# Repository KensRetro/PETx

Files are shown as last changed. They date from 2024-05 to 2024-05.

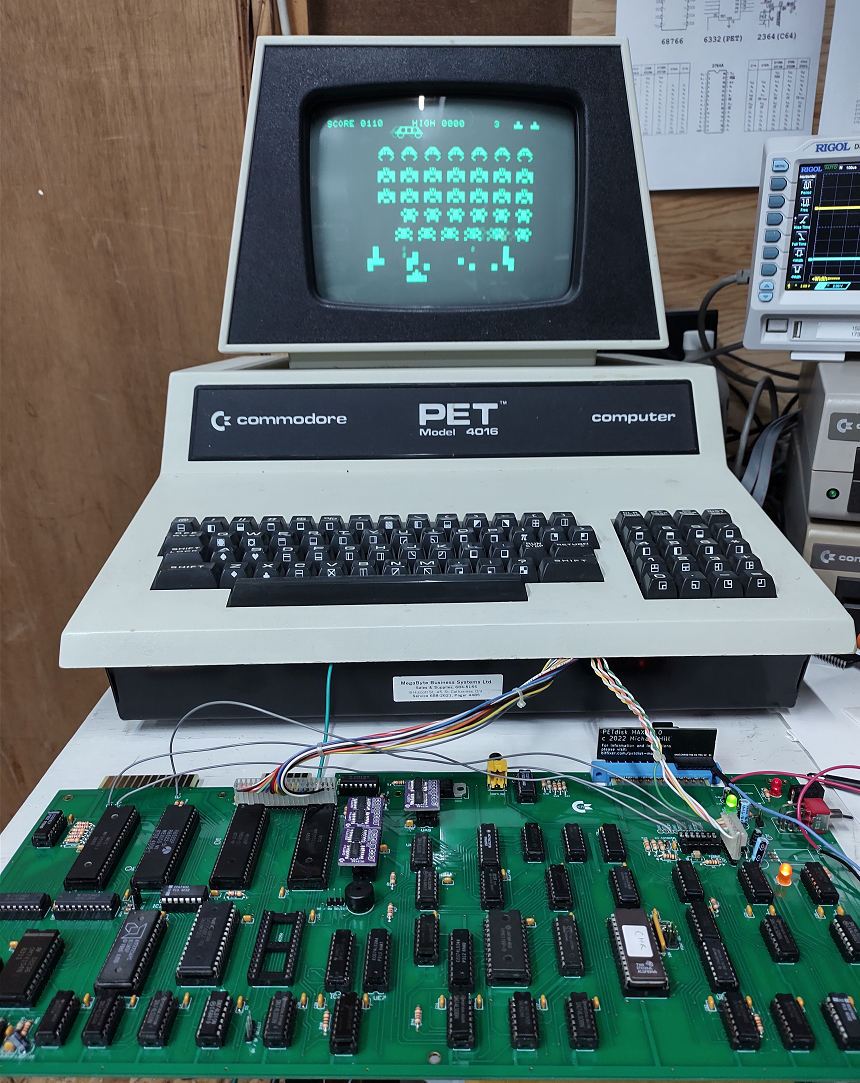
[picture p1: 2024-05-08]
Pictures/Prototype_testing1.png

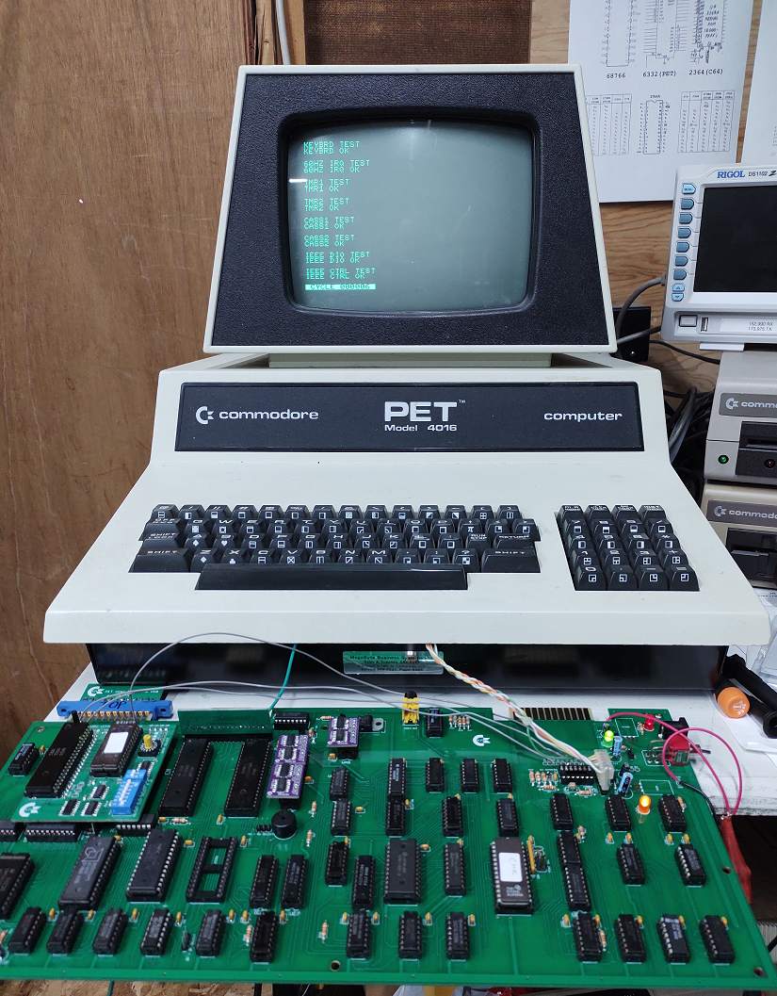
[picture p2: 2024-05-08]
Pictures/Prototype_testing2.png

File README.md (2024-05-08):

# This project is currently partially complete, please read the following carefully and make an informed decision before you attempt to build it.

I like to provide schematics in Eagle (version 7) because that's what I have used for years at work and it's easy to upgrade the files to 
newer versions or Kicad etc.  It's just a comfort thing for me, but if you change to another format please be sure to carefully check 
that everything looks as it should - conversions don't always go cleanly.  

DISCLAIMER: All information is provided 'AS-IS", I have tried to be as accurate as possible but that doesn't mean there are no mistakes. 
Any errors or omissions etc. are your own responsibility.  

# Project Notes : C64 sized PET - PETx

The prototype is based on the the 9 inch screen version of the PET (board #320349) so no CRTC chip is needed.
I added the video circuit similar to the ones posted around the net
It was also decided to go with a more similar to original re-creation as it makes it easier to substitute parts etc. 
and compatibility remains quite good.

# Changes / Updates in this version (PROTOTYPE): 
1. Added connections for RESET (momentary switch)
2. Added NO_ROM line for diagnostics
3. Added peizo buzzer for standard PET sounds
4. Added Video output circuit - HORIZ/VERT/VIDEO signals no longer attached to USER PORT (I left connection points but will need a
   jumper to connect if needed. This was done in order to facilitate routing, these lines to the user port are normally used for a
   video output circuit, since it's already on-board, it's not likely needed)
5. Added GRAPHIC signal to USER PORT (similar to 12" screen versions)
6. Removed memory expansion connections, definitely won't fit on the board and no known expansion units will fit in the case anyway
7. Changed Video RAM to a single 6116 chip instead of 2 x 2114 (availability)
8. Change ROM set to a single chip, added necessary decoding logic so I/O chip memory is not replaced.
9. Added a jumper to allow multiple ROM sets built in (could be connected to a switch)
10. Changed RAM to a single chip of 32K, this also allowed removal of +12V and -5V supplies and associated components saving a lot of space.
11. Removed CASSETTE #2 as it is rarely used, connection points are still available but no driver for the tape motor was included.
    Connection would have to be wired off the board if needed.
12. Added a couple sets of connection points for +5V and GND for add-ons (normally CASSETTE #1/2 was used for this)
13. Added optional 2nd RAM chip mapped into 9000-FFFF range, jumper (or switch configurable) for only being active over 9000-AFFF or 9000-FFFF for soft ROM option
14. Added option for 2nd RAM (9000-FFFF) to be "READ ONLY" or "READ WRITE"
15. Terminated unused gates to minimize potential noise.
16. Changed ROM socket to allow use of SST39SF010A as well as 27256 (4 ROM sets, Flash ROM, externally programmable)
17. Changed Character ROM to allow more fonts and use of SST39SF010A as well as 27xxx series Eproms.
18. Added power switch & connector that should fit into the existing C64 bracket  (if used)
19. Added access to unused RAM in 8000 area (8400-8FFF)
    
# Potential upgrades not currently incorporated:
(Feel free to suggest others)
1. Add a writable latch that controls some of the dipswitch selectable features above
    
# More Notes:
This project is a PET 2001, 9 inch screen version (started with schematic 320349). This model was chosen for 2 reasons, 
first, a CRTC chip is not required and second, it outputs a near standard video signal with the included interface.
The Intent was to make it fit into a C64 / VIC-20 case.
In order to Achieve this a reduced footprint was needed, so the changes above were implemented.
The parallel and Cassette #1 ports were designed to line up in the same place as the C64/VIC20 version.
The video output appears where the RF output jack was on the C64. This area is in the cartridge slot on the VIC20
The IEEE port appears where the C64 cartridge port was and covers the left 2/3 of the VIC 20 cartridge area.
The placements mean that no/few modifications are needed to the case of the C64 or VIC 20 to fit the board in.
Unfortunately, the power switch and joystick area ends up wide open, with the power switch and power cord coming out in that area.
Perhaps a 3D printed cover could be fashioned as a replacement.
Many other possible upgrades were considered but due to a lack of space and complexity, were rejected (for the prototype run at least).
Perhaps other additions or changes could be incorporated in a future version.
This project depends on the Commodore original prints being correct, some minor corrections were caught, but they were used as a base to start.
The Chip ID's on the silkscreen are those from the original PET layout and start with Uxxx, Chips that start with ICxx are additions or changes 
that have been incorporated to slim the footprint or facilitate routing.
Various keyboard options were considered but again, for the prototype at least, were sticking with a standard C64/VIC20 keyboard and a patched 
version of the edit ROM (or some other available hardware solution)

# BEFORE YOU BUILD:
Some of the parts are near impossible to find, specifically 3446 chips, 74177 chips, and 74154 chips in a DIP package. 
I have a replacement sub-board for the 3446 chips in another repository that has been tested successfully.
You can use 74197 chips as a direct replacement for the 74177, but they are very rare as well.
You can use a newer version of the 74154 chip but it seems to only be available in a SMT version, therefore an adaptor board may need to be created.

# PROTOTYPE VERSION:
This version has been created and tested.  Some small errors were corrected with bodge wires and an added chip and and it seems to function well and passes the diagnostic 
cartridge tests consistantly.

# RELEASE VERSION:
This version HAS NOT been created or tested (I didn't really need another hanging around)
The errors have been corrected in the schematic and board files and Gerbers have been created.

Changes to this version (REV.1) also include the following:
1) Added solder jumpers to allow WD6502 to be used
2) Changed Power supply to 1 regulator
   
TO DO:
1. check/fix alignment of mounting holes to C64 case (Not checked or tested in VIC20 case at this time)

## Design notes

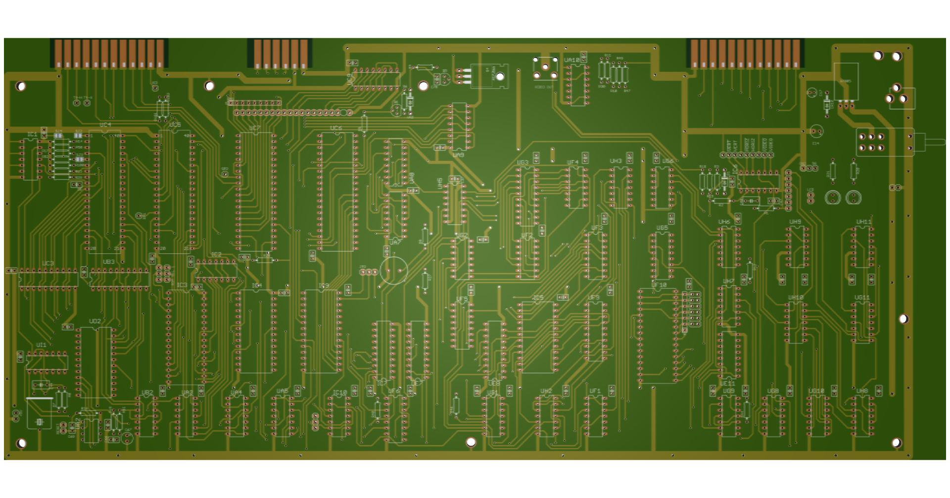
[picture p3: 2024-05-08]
Pictures/board(Rev1).png

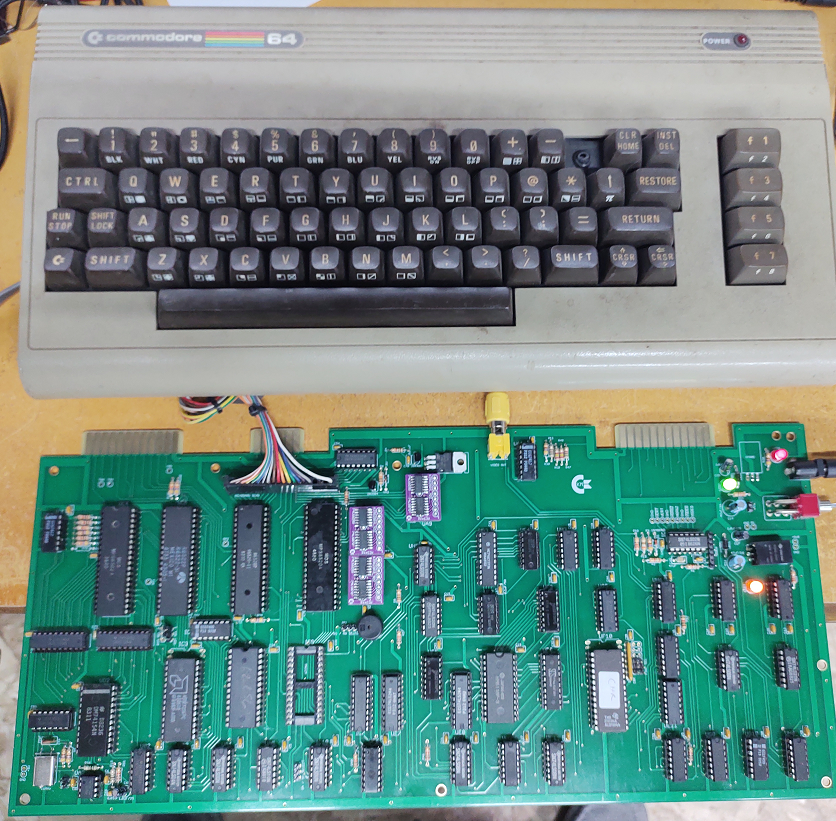
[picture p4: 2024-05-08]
Pictures/Prototype.png

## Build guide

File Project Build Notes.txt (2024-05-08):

PETx Construction and testing notes:

(*** = Updateed note)

You will need basic soldering and electronic skills to complete this project!!!

*** including an EPROM burner or EEPROM writer if that's what you wish to use, the board should accept 27xxx series EPROMS, SST39SF010A Flash memory or compatible, for both the main ROM and Character Generator with a jumper setting - let me know and I will send the configuration details for which ever you wish to use.

At this time I have tried the board with limited variety of optional chips, some seem more critical than others, please be aware this may affect your results.
The board has passed 100 cycles of the Commodore diagnostic test and has been tried with a 2031 disk drive and PETdisk MAX successfully.
Various games have been tested using both the standard PET keyboard and with a revised ROM, a C64 keyboard.
The C64 keyboard solution seems to need a bit more work for my liking.

*** The replacement edit ROM I found online which is supposed to substitute for a C64 style keyboard leaves a lot to be desired. There seems to be no access to shifted characters and the run/stop key doesn't work (however the K key seems to work in it's place to stop execution for some reason)  If you can test with an actual PET keyboard to start it may be beneficial.  I have 2 options to correct this, first, we can try to fix the current replacement ROM or I have created a small secondary project to replace the PET keyboard with a PC (PS2 style) keyboard that seems to function quite well - Details in another repository
FYI: if you use the C64 keyboard, use right shift and F1 to move and space to fire in Space Invaders :)

There are a few rare (obsolete) chips that you will need to source to complete this project, Sorry but I can't help, I have no spares either.
Attached is the parts list, please make sure you can get the necessary parts (at a price you are comfortable with) BEFORE ordering.

The board seems to be a bit finicky about certain chips, I had to try a different brand and speed or RAM chips to get things to work properly (slower RAM worked better, not sure why), but i'm looking into it.

*** I found the issue with the RAM.  Basically there was a small timing issue which, if you are interested, you can learn about in this video : https://www.youtube.com/watch?v=i_wrxBdXTgM (start around 22:00 if you don't want to watch the whole thing)  - Ben Eater has produced a selection of really great videos dealing with building around a 6502, I enjoyed watching these and some of his other well explained videos.  The issue was fixed exactly as Ben fixed it (he's actually used the exact same chips as I have, coincedentally) by adding an extra gate into the circuit. 

Be prepared to do a lot of soldering, it's all through hole so it's easy, but it's a large board and it's a good idea to do the job carefully and well to avoid issues.
I'm still trying low power versions of most chips (awaiting another parts order) to try and get the power supply less loaded.

*** I swapped out MOST of the chips for 74HCTxxx versions and it brought the power consumption down from 1.0 Amp to around 600 mA (on the 5V rail), my supply feeding the board which is now modified for a single regulator actually reads around 380 mA @ 9VDC input to the board. NOTE: There were a few chips that did not seem to work well as HCT (or that I could not find HCT replacement for) so they remain the normal ones.  Interestingly and as a bonus, most HCT versions seemd to be less expensive than their regular counterparts. 

With the factory designated chip versions, the board requires about 1 amp @ 5VDC - I designed it with 2 (2 amp) regulators because the original board had 2.
I found out this is not necessary and with a jumper you can get it down to 1. The regulator is good up to 15 Volts, so a 1 amp supply at 10-12VDC should do it.

There are some chip substitutions that might be easier to find:
For 74177 you can use 74197 - I found DM74197N chips - a little more power needed but basically the same chip.
For 74LS157 I used 74LS257 chips I happen to have on-hand
For 74154 you might have a hard time finding the 28 pin DIP needed, SMT versions seem readily available. 
I have a converter board for these in another repository
For MC3446N (IEEE drivers) I made a converter board to substitute that seems to work well, less drive but unless you are hooking up many devices it likely won't matter.
I have a few of those left, let me know if you need them, (no charge,) 3 are needed for the project
You'll also need a 6502, 6522 and 2 of 6520 chips - These also are getting rare.

A few other parts may need to be figured out or are optional:
such as then Power jack, power switch, on board LED's, expansion RAM (NOTE: so far this option is untested)

*** I have tested the expansion RAM and with the same fix as is needed for the main RAM, plus 1 other minor tweak, it seems to work well. It is entirely optional but will give you RAM from $8800 - $AFFF with the ability to switch to read only, allowing you to load option ROMS in this area and make them appear as read-only to the system.  I have also enabled the excess RAM in the video circuit (by default) to allow access to RAM from the end of video $8400 - $8800.  I have not tried the RAM above $B000, it's there and should record anything written to it (poked in) but will not respond until you do 2 things: 1. Disable the normal ROM (using the !NOROM signal) and 2. Enable the RAM to respond with the correct jumper.  I can explain in detail if you wish, just let me know,  This switch is a bit tricky as it requires the cpu to not be accessing ROM while it switches, so a small bit of assembler code is required with a 2 pole switch to change the mentioned signals; I have tested this minimally with success.

Build Notes:

I used sockets for EVERY chip, this is a good idea! Please use good quality sockets for the 6502/6522/6520's/RAM/ROM/CHARGEN sockets at a minimum - Machine pin type seem to work well for chips that may be changed occasionally (especially during troubleshooting).
*** Machine pin sockets work great for NEW parts, not so well for de-soldered ones, something to keep in mind. 
Also note that some component footprints might not be quite correct (capacitor sizes and that sort of thing) as I used footprints that suited the parts I had on-hand.
Some (bottom) mounting holes don't quite line up with C64 case.

Holes are provided to be able to use the metal bracket off a C64 board (power switch end) if you can find one.
A jumper (and a cut trace) is needed on the RAM chip
1 Regulator needed only (install jumper to other footprint)
Buzzer doesn't quit fit properly, need to adjust footprint

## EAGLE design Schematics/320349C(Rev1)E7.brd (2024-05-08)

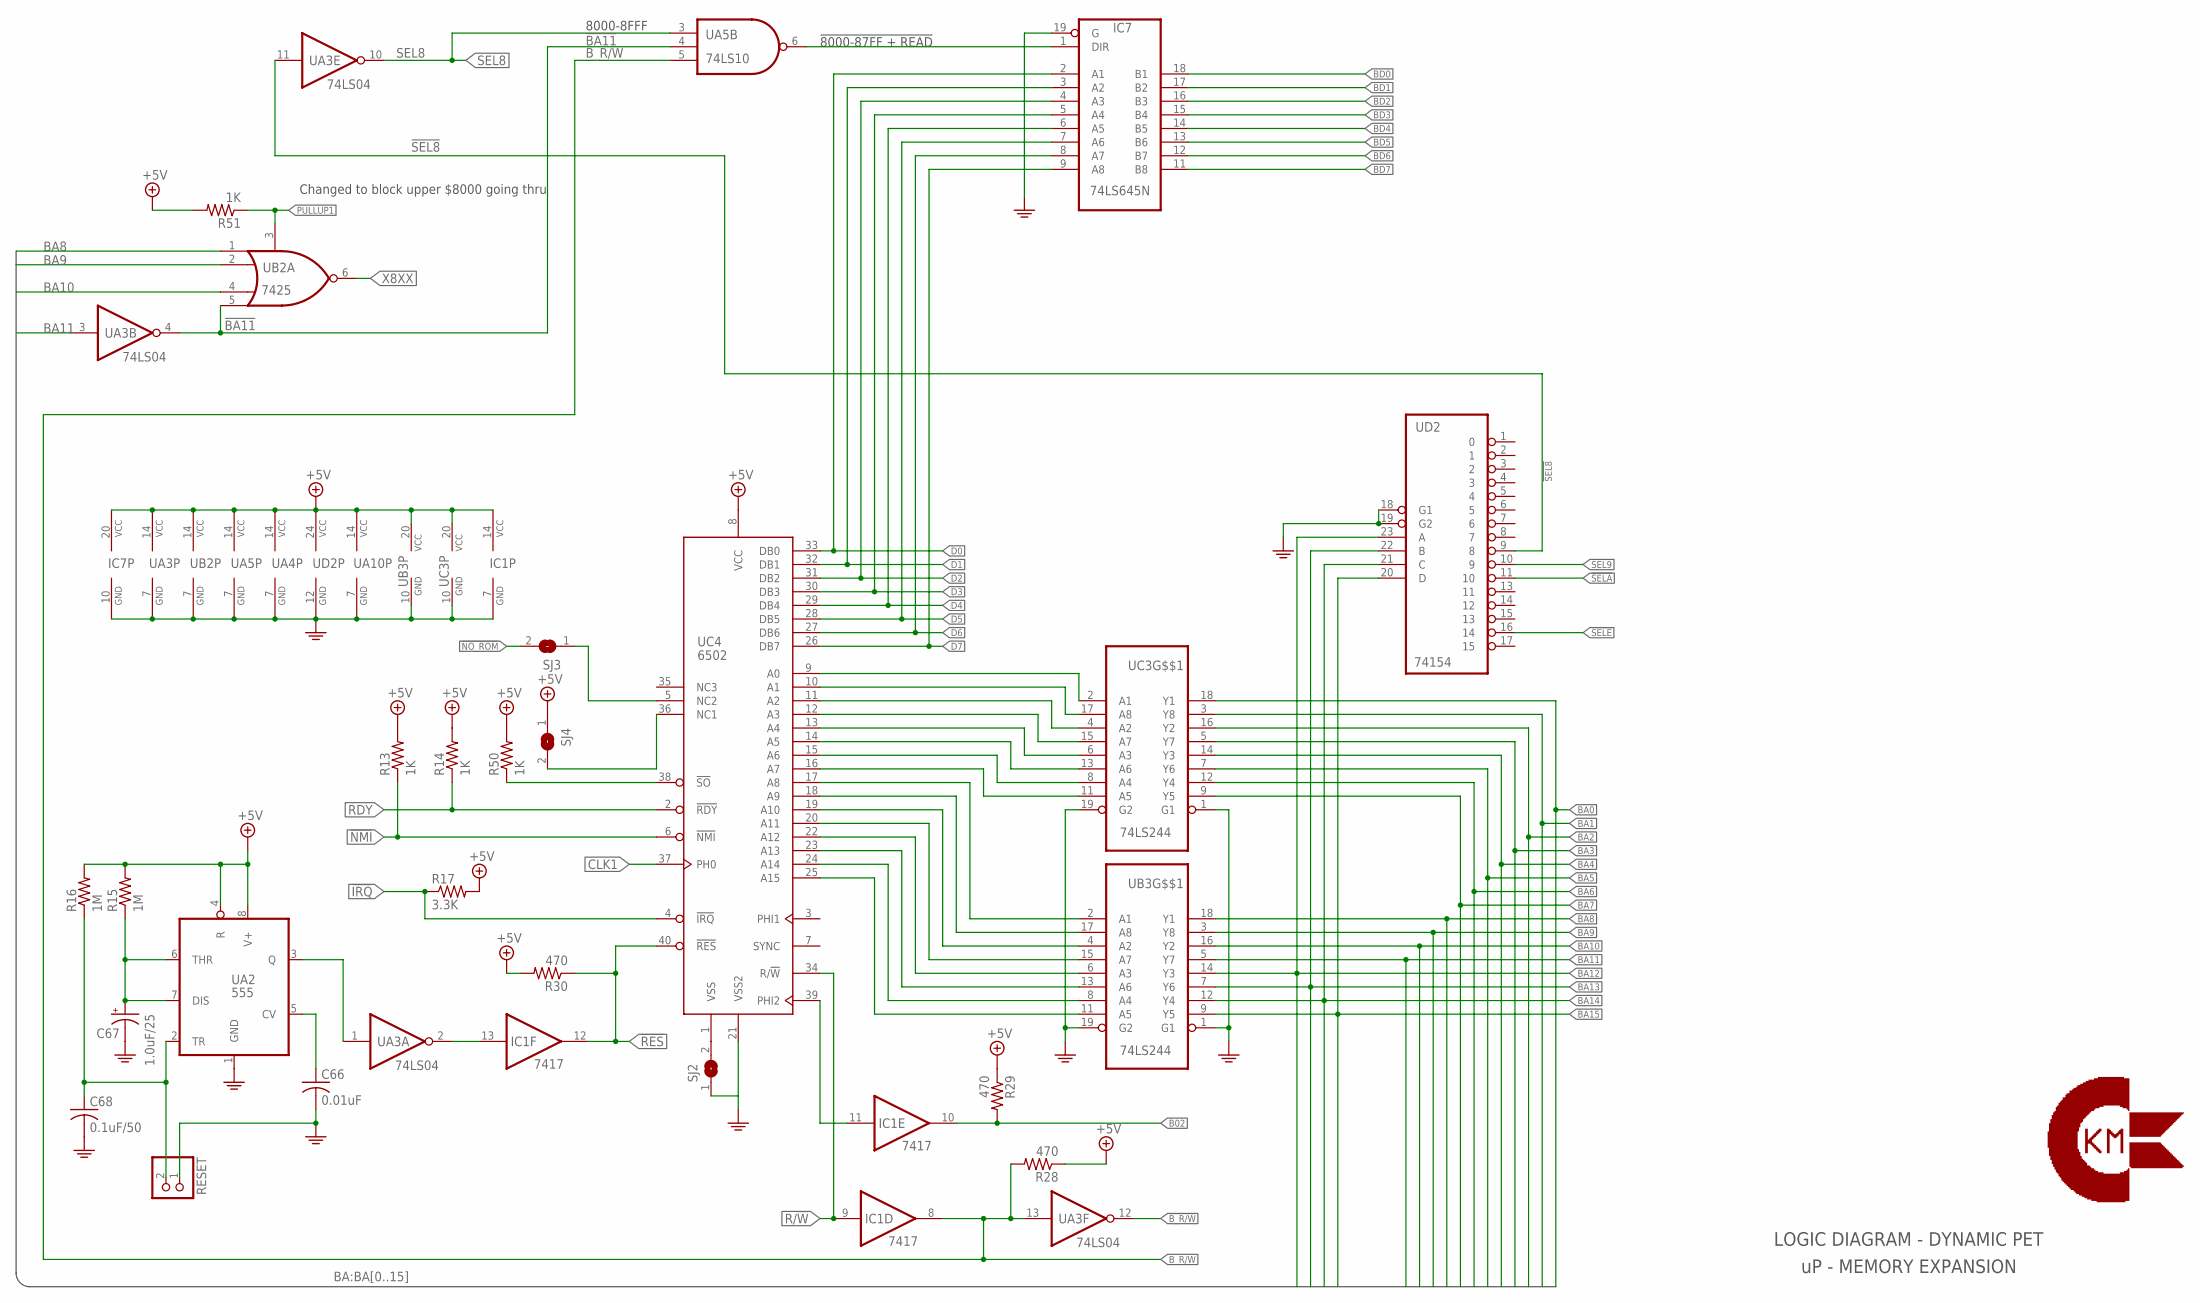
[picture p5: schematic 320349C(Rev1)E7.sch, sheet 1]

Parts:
C66: 0.01uF; C025-025X050
C67: 1.0uF/25; E2,5-5
C68: 0.1uF/50; C025-025X050
IC1: 7417; DIL14
IC7: 74LS645N; DIL20
R13, R14, R50, R51: 1K; 0207/10
R15, R16: 1M; 0207/10
R17: 3.3K; 0207/10
R28, R29, R30: 470; 0207/10
RESET: PINHD-1X2; 1X02
SJ2, SJ3, SJ4: SJ
UA2: 555; DIL08
UA3: 74LS04; DIL14
UA4: 74LS00; DIL14
UA5: 74LS10; DIL14
UA10: 7417; DIL14
UB2: 7425; DIL14
UB3: 74LS244; DIL20
UC3: 74LS244; DIL20
UC4: 6502; DIP40
UD2: 74154; DIL24-6

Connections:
!BA11: UA3.4 (O), UA5.4 (I1), UB2.5 (I3); also elsewhere on the board
!B_R/W: UA3.12 (O); also elsewhere on the board
!IRQ: R17.1, UC4.4 (!IRQ); also elsewhere on the board
!NMI: R13.1, UC4.6 (!NMI)
!NO_ROM: SJ3.2; also elsewhere on the board
!RES: IC1.12 (O), R30.1, UC4.40 (!RES); also elsewhere on the board
!SEL8: UA3.11 (I), UD2.9 (8); also elsewhere on the board
!SEL9: UD2.10 (9); also elsewhere on the board
!SELA: UD2.11 (10); also elsewhere on the board
!SELE: UD2.16 (14); also elsewhere on the board
+5V: IC1.14 (VCC), IC7.20 (VCC), R13.2, R14.2, R15.2, R16.2, R17.2, R28.1, R29.1, R30.2, R50.2, R51.2, SJ4.1, UA2.4 (R), UA2.8 (V+), UA3.14 (VCC), UA4.14 (VCC), UA5.14 (VCC), UA10.14 (VCC), UB2.14 (VCC), UB3.20 (VCC), UC3.20 (VCC), UC4.8 (VCC), UD2.24 (VCC); also elsewhere on the board
AB0: UC3.2 (A1), UC4.9 (A0)
AB1: UC3.17 (A8), UC4.10 (A1)
AB2: UC3.4 (A2), UC4.11 (A2)
AB3: UC3.15 (A7), UC4.12 (A3)
AB4: UC3.6 (A3), UC4.13 (A4)
AB5: UC3.13 (A6), UC4.14 (A5)
AB6: UC3.8 (A4), UC4.15 (A6)
AB7: UC3.11 (A5), UC4.16 (A7)
AB8: UB3.2 (A1), UC4.17 (A8)
AB9: UB3.17 (A8), UC4.18 (A9)
AB10: UB3.4 (A2), UC4.19 (A10)
AB11: UB3.15 (A7), UC4.20 (A11)
AB12: UB3.6 (A3), UC4.22 (A12)
AB13: UB3.13 (A6), UC4.23 (A13)
AB14: UB3.8 (A4), UC4.24 (A14)
AB15: UB3.11 (A5), UC4.25 (A15)
B02: IC1.10 (O), R29.2; also elsewhere on the board
BA0: UC3.18 (Y1); also elsewhere on the board
BA1: UC3.3 (Y8); also elsewhere on the board
BA2: UC3.16 (Y2); also elsewhere on the board
BA3: UC3.5 (Y7); also elsewhere on the board
BA4: UC3.14 (Y3); also elsewhere on the board
BA5: UC3.7 (Y6); also elsewhere on the board
BA6: UC3.12 (Y4); also elsewhere on the board
BA7: UC3.9 (Y5); also elsewhere on the board
BA8: UB2.1 (I0), UB3.18 (Y1); also elsewhere on the board
BA9: UB2.2 (I1), UB3.3 (Y8); also elsewhere on the board
BA10: UB2.4 (I2), UB3.16 (Y2); also elsewhere on the board
BA11: UA3.3 (I), UB3.5 (Y7); also elsewhere on the board
BA12: UB3.14 (Y3), UD2.23 (A); also elsewhere on the board
BA13: UB3.7 (Y6), UD2.22 (B); also elsewhere on the board
BA14: UB3.12 (Y4), UD2.21 (C); also elsewhere on the board
BA15: UB3.9 (Y5), UD2.20 (D); also elsewhere on the board
BD0: IC7.18 (B1); also elsewhere on the board
BD1: IC7.17 (B2); also elsewhere on the board
BD2: IC7.16 (B3); also elsewhere on the board
BD3: IC7.15 (B4); also elsewhere on the board
BD4: IC7.14 (B5); also elsewhere on the board
BD5: IC7.13 (B6); also elsewhere on the board
BD6: IC7.12 (B7); also elsewhere on the board
BD7: IC7.11 (B8); also elsewhere on the board
B_R/W: IC1.8 (O), R28.2, UA3.13 (I), UA5.5 (I2); also elsewhere on the board
CLK1: UC4.37 (PH0); also elsewhere on the board
CLK2: IC1.11 (I), UC4.39 (PHI2)
D0: IC7.2 (A1), UC4.33 (DB0); also elsewhere on the board
D1: IC7.3 (A2), UC4.32 (DB1); also elsewhere on the board
D2: IC7.4 (A3), UC4.31 (DB2); also elsewhere on the board
D3: IC7.5 (A4), UC4.30 (DB3); also elsewhere on the board
D4: IC7.6 (A5), UC4.29 (DB4); also elsewhere on the board
D5: IC7.7 (A6), UC4.28 (DB5); also elsewhere on the board
D6: IC7.8 (A7), UC4.27 (DB6); also elsewhere on the board
D7: IC7.9 (A8), UC4.26 (DB7); also elsewhere on the board
GND: C66.2, C67.-, C68.2, IC1.7 (GND), IC7.10 (GND), IC7.19 (G), RESET.1, SJ2.1, UA2.1 (GND), UA3.7 (GND), UA4.7 (GND), UA5.7 (GND), UA10.7 (GND), UB2.7 (GND), UB3.1 (G1), UB3.10 (GND), UB3.19 (G2), UC3.1 (G1), UC3.10 (GND), UC3.19 (G2), UC4.21 (VSS2), UD2.12 (GND), UD2.18 (G1), UD2.19 (G2); also elsewhere on the board
unnamed: IC7.1 (DIR), UA5.6 (O)
unnamed: R50.1, UC4.38 (!SO)
unnamed: C66.1, UA2.5 (CV)
unnamed: C67.+, R15.1, UA2.6 (THR), UA2.7 (DIS)
unnamed: C68.1, R16.1, RESET.2, UA2.2 (TR)
unnamed: IC1.13 (I), UA3.2 (O)
unnamed: UA2.3 (Q), UA3.1 (I)
unnamed: SJ3.1, UC4.5 (NC2)
unnamed: SJ4.2, UC4.36 (NC1)
unnamed: SJ2.2, UC4.1 (VSS)
PULLUP1: R51.1, UB2.3 (G); also elsewhere on the board
R/!W: IC1.9 (I), UC4.34 (R/!W); also elsewhere on the board
RDY: R14.1, UC4.2 (!RDY)
SEL8: UA3.10 (O), UA5.3 (I0); also elsewhere on the board
X8XX: UB2.6 (O); also elsewhere on the board

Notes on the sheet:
LOGIC DIAGRAM - DYNAMIC PET
uP - MEMORY EXPANSION
8000-8FFF
!8000-87FF + READ
Changed to block upper $8000 going thru

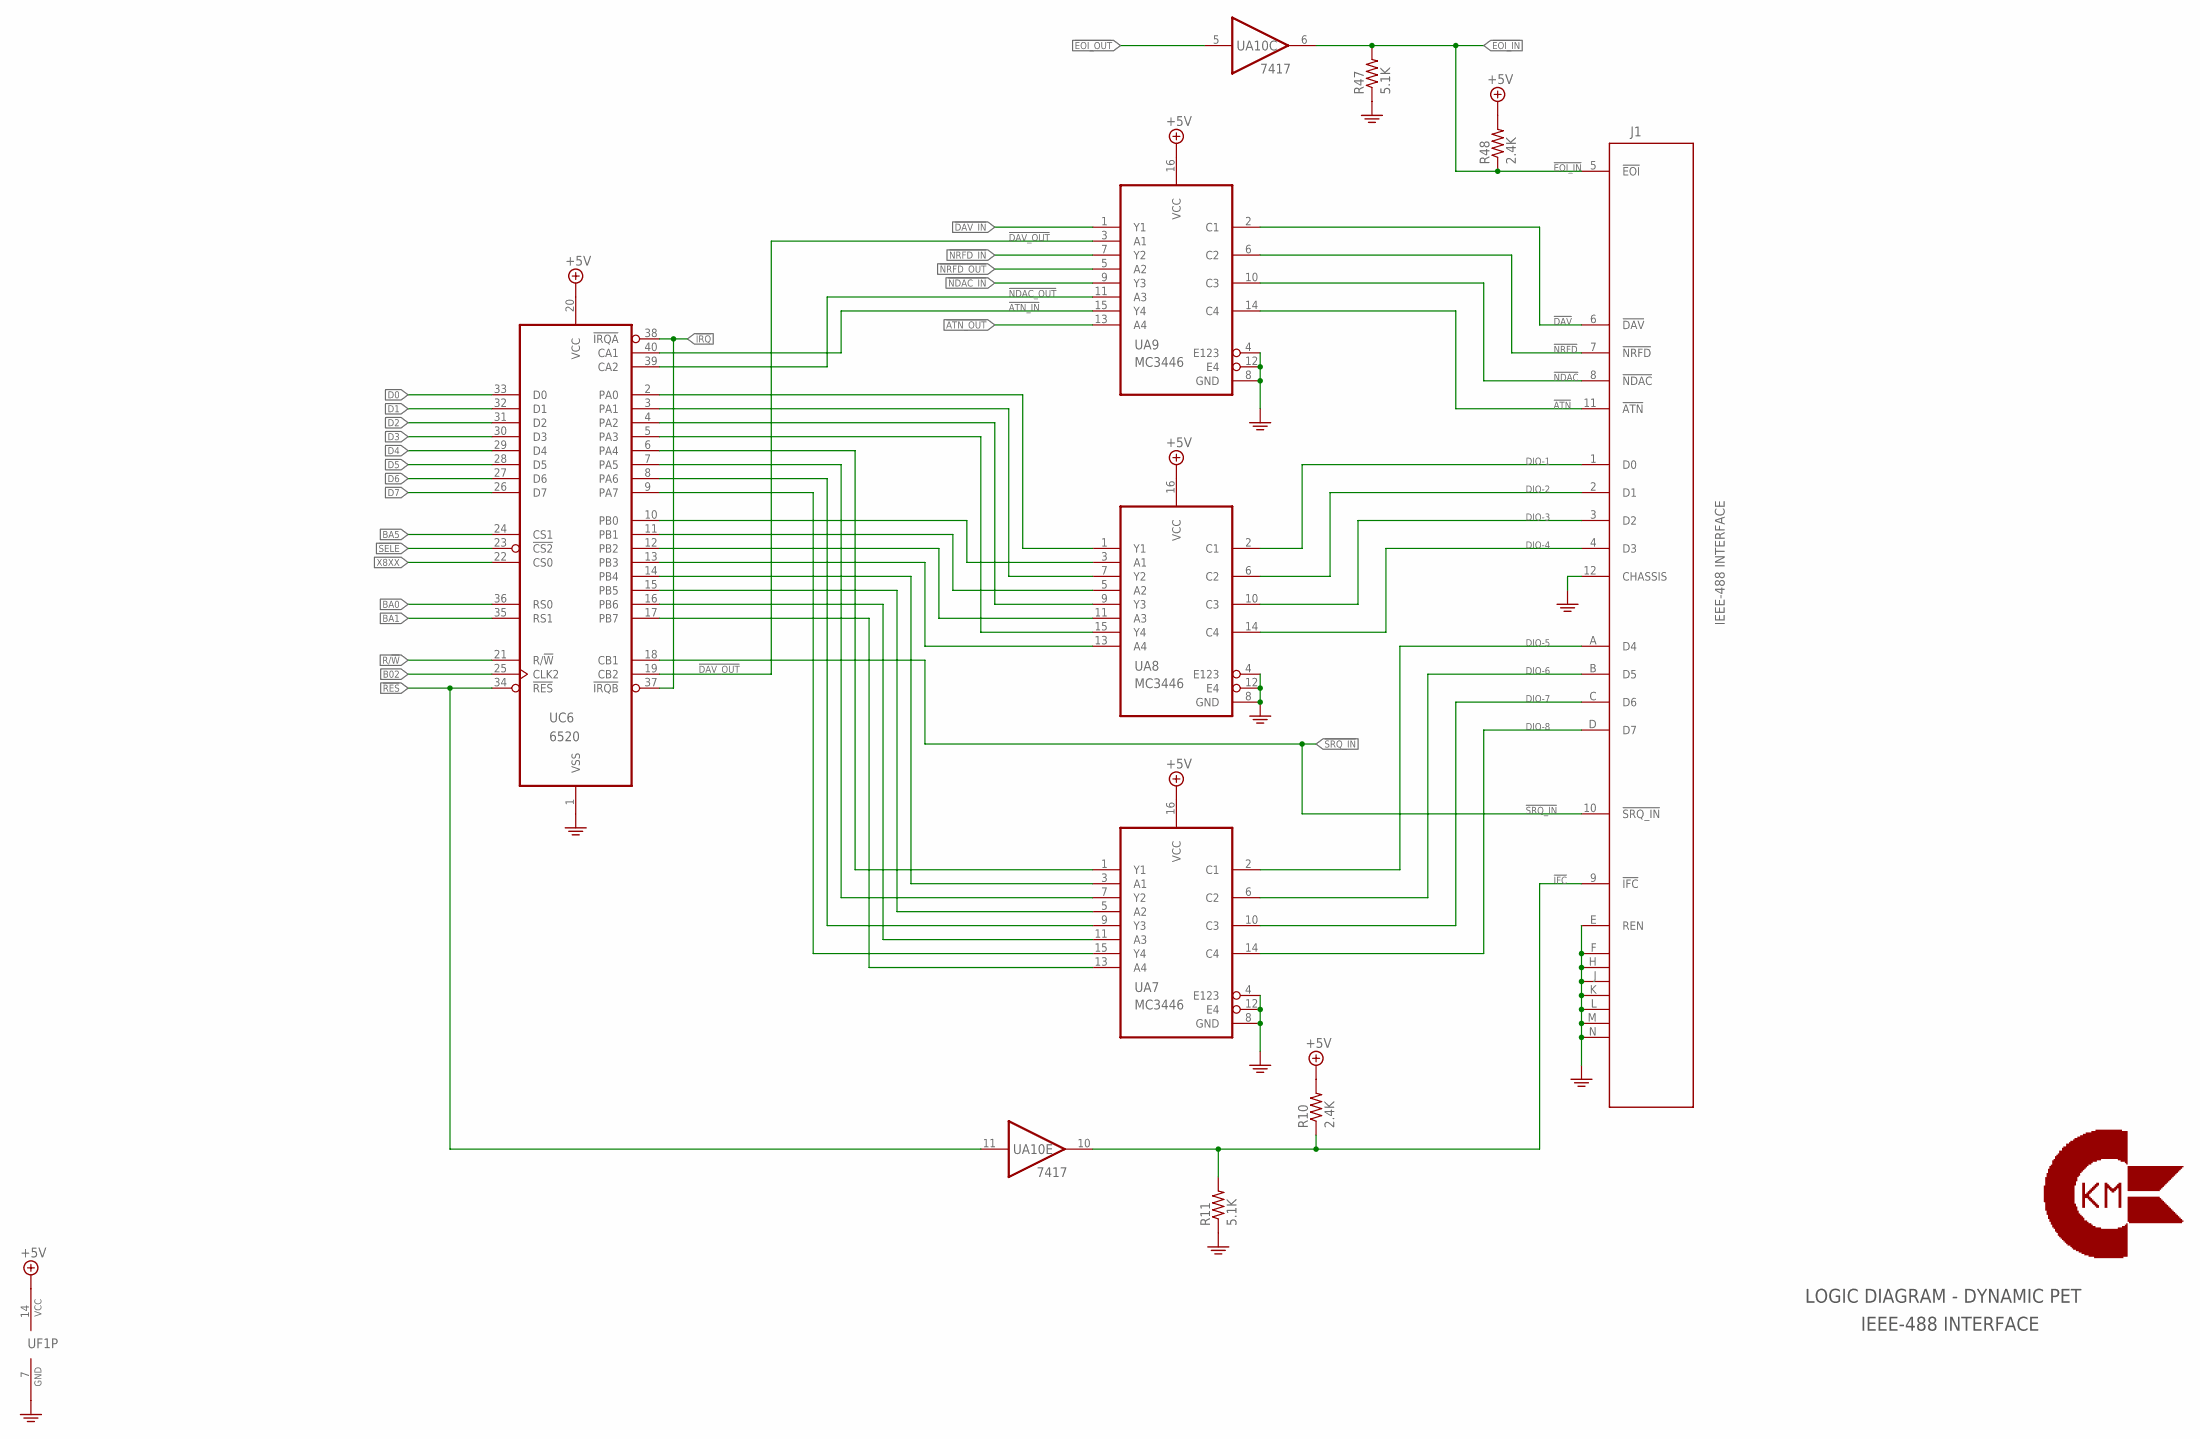
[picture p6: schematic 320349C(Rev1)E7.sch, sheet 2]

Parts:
J1: IEEE-488 INTERFACE; UPS24EDGE
R10, R48: 2.4K; 0207/10
R11, R47: 5.1K; 0207/10
U$32: CBM-XL
UA7, UA8, UA9: MC3446; DIL16
UA10: 7417; DIL14
UC6: 6520; DIL40
UF1: 74LS08; DIL14

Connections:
!ATN: J1.11 (!ATN), UA9.14 (C4)
!ATN_IN: UA9.15 (Y4), UC6.40 (CA1)
!ATN_OUT: UA9.13 (A4); also elsewhere on the board
!DAV: J1.6 (!DAV), UA9.2 (C1)
!DAV_IN: UA9.1 (Y1); also elsewhere on the board
!DAV_OUT: UA9.3 (A1), UC6.19 (CB2)
!EOI_IN: J1.5 (!EOI), R47.2, R48.1, UA10.6 (O); also elsewhere on the board
!EOI_OUT: UA10.5 (I); also elsewhere on the board
!IFC: J1.9 (!IFC), R10.1, R11.2, UA10.10 (O)
!IRQ: UC6.37 (!IRQB), UC6.38 (!IRQA); also elsewhere on the board
!NDAC: J1.8 (!NDAC), UA9.10 (C3)
!NDAC_IN: UA9.9 (Y3); also elsewhere on the board
!NDAC_OUT: UA9.11 (A3), UC6.39 (CA2)
!NRFD: J1.7 (!NRFD), UA9.6 (C2)
!NRFD_IN: UA9.7 (Y2); also elsewhere on the board
!NRFD_OUT: UA9.5 (A2); also elsewhere on the board
!RES: UA10.11 (I), UC6.34 (!RES); also elsewhere on the board
!SELE: UC6.23 (!CS2); also elsewhere on the board
!SRQ_IN: J1.10 (!SRQ_IN), UC6.18 (CB1); also elsewhere on the board
+5V: R10.2, R48.2, UA7.16 (VCC), UA8.16 (VCC), UA9.16 (VCC), UC6.20 (VCC), UF1.14 (VCC); also elsewhere on the board
B02: UC6.25 (CLK2); also elsewhere on the board
BA0: UC6.36 (RS0); also elsewhere on the board
BA1: UC6.35 (RS1); also elsewhere on the board
BA5: UC6.24 (CS1); also elsewhere on the board
D0: UC6.33 (D0); also elsewhere on the board
D1: UC6.32 (D1); also elsewhere on the board
D2: UC6.31 (D2); also elsewhere on the board
D3: UC6.30 (D3); also elsewhere on the board
D4: UC6.29 (D4); also elsewhere on the board
D5: UC6.28 (D5); also elsewhere on the board
D6: UC6.27 (D6); also elsewhere on the board
D7: UC6.26 (D7); also elsewhere on the board
DI-1: UA8.1 (Y1), UC6.2 (PA0)
DI-2: UA8.7 (Y2), UC6.3 (PA1)
DI-3: UA8.9 (Y3), UC6.4 (PA2)
DI-4: UA8.15 (Y4), UC6.5 (PA3)
DI-5: UA7.1 (Y1), UC6.6 (PA4)
DI-6: UA7.7 (Y2), UC6.7 (PA5)
DI-7: UA7.9 (Y3), UC6.8 (PA6)
DI-8: UA7.15 (Y4), UC6.9 (PA7)
DIO-1: J1.1 (D0), UA8.2 (C1)
DIO-2: J1.2 (D1), UA8.6 (C2)
DIO-3: J1.3 (D2), UA8.10 (C3)
DIO-4: J1.4 (D3), UA8.14 (C4)
DIO-5: J1.A (D4), UA7.2 (C1)
DIO-6: J1.B (D5), UA7.6 (C2)
DIO-7: J1.C (D6), UA7.10 (C3)
DIO-8: J1.D (D7), UA7.14 (C4)
DO-1: UA8.3 (A1), UC6.10 (PB0)
DO-2: UA8.5 (A2), UC6.11 (PB1)
DO-3: UA8.11 (A3), UC6.12 (PB2)
DO-4: UA8.13 (A4), UC6.13 (PB3)
DO-5: UA7.3 (A1), UC6.14 (PB4)
DO-6: UA7.5 (A2), UC6.15 (PB5)
DO-7: UA7.11 (A3), UC6.16 (PB6)
DO-8: UA7.13 (A4), UC6.17 (PB7)
GND: J1.12 (CHASSIS), J1.E (REN), J1.F (18), J1.H (19), J1.J (20), J1.K (21), J1.L (22), J1.M (23), J1.N (24), R11.1, R47.1, UA7.4 (E123), UA7.8 (GND), UA7.12 (E4), UA8.4 (E123), UA8.8 (GND), UA8.12 (E4), UA9.4 (E123), UA9.8 (GND), UA9.12 (E4), UC6.1 (VSS), UF1.7 (GND); also elsewhere on the board
R/!W: UC6.21 (R/!W); also elsewhere on the board
X8XX: UC6.22 (CS0); also elsewhere on the board

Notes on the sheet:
LOGIC DIAGRAM - DYNAMIC PET
IEEE-488 INTERFACE

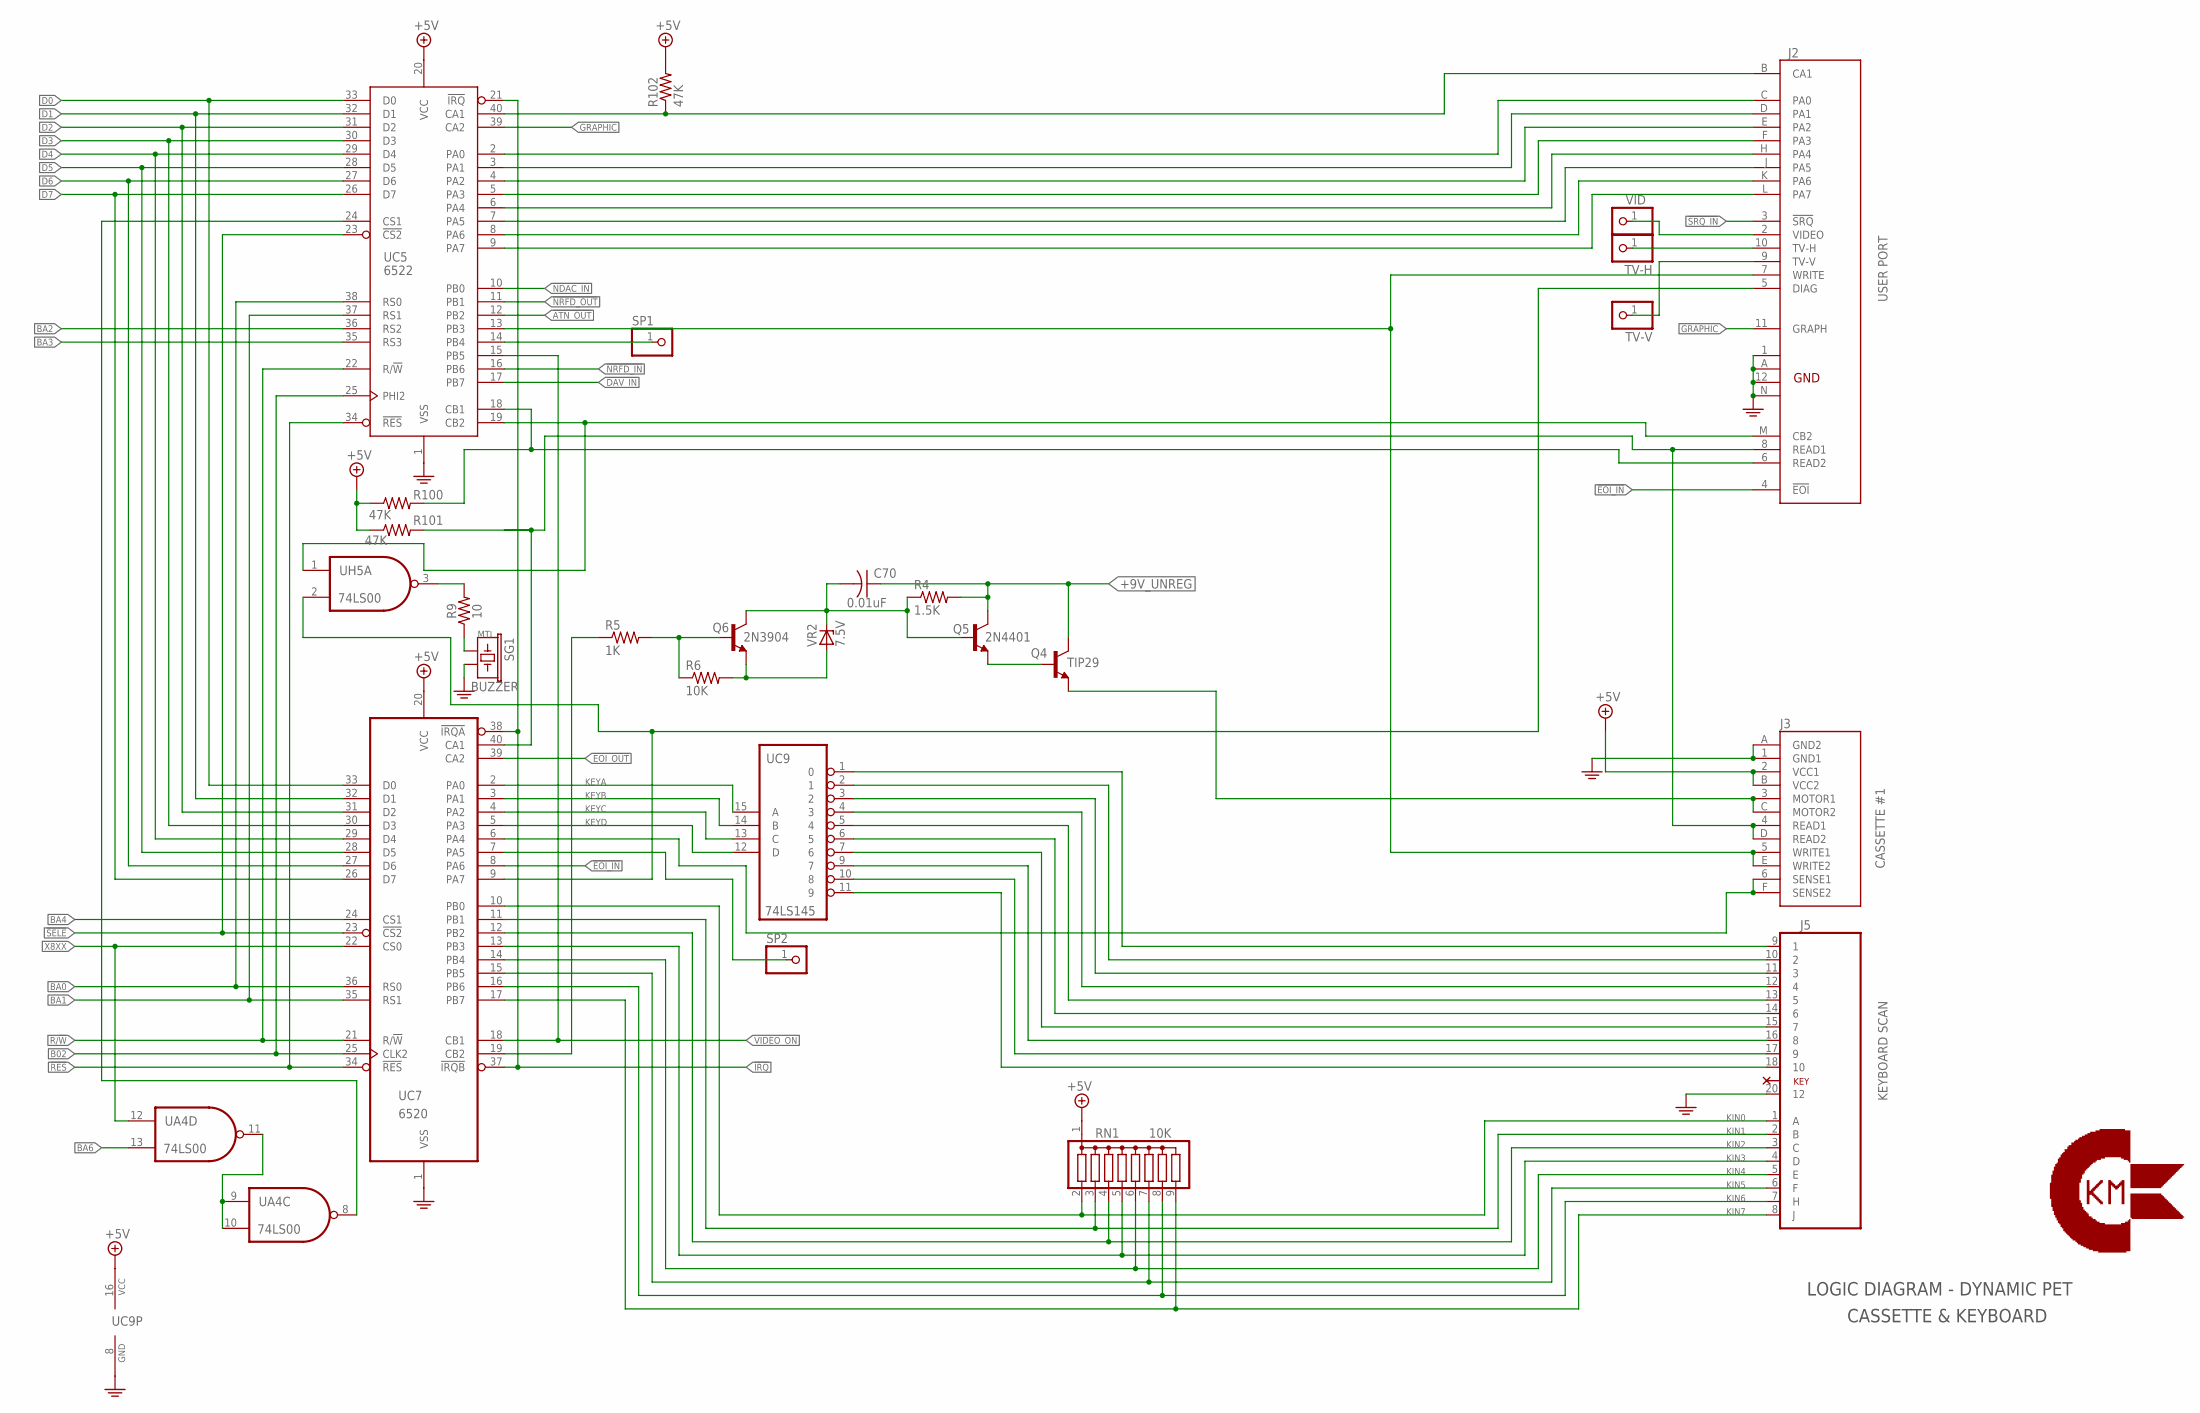
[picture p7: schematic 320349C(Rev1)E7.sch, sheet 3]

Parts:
C70: 0.01uF; C025-025X050
J2: USER PORT; UPS24EDGE
J3: CASSETTE #1; CASSETTE
J5: KEYBOARD SCAN; PET_KEYBOARD
Q4: TIP29; TO220
Q5: 2N4401; TO92
Q6: 2N3904; TO92
R4: 1.5K; 0207/10
R5: 1K; 0207/10
R6: 10K; 0207/10
R9: 10; 0207/10
R100, R101, R102: 47K; 0207/10
RN1: 10K; SIL9
SG1: BUZZER; BUZZER-12MM
SP1, SP2: PINHD-1X1; 1X01
TV-H: PINHD-1X1; 1X01
TV-V: PINHD-1X1; 1X01
UA4: 74LS00; DIL14
UC5: 6522; DIP40
UC7: 6520; DIL40
UC9: 74LS145; DIL16
UH5: 74LS00; DIL14
VID: PINHD-1X1; 1X01
VR2: 7.5V; DO41Z10

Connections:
!ATN_OUT: UC5.12 (PB2); also elsewhere on the board
!DAV_IN: UC5.17 (PB7); also elsewhere on the board
!EOI_IN: J2.4 (!EOI), UC7.8 (PA6); also elsewhere on the board
!EOI_OUT: UC7.39 (CA2); also elsewhere on the board
!IRQ: UC5.21 (!IRQ), UC7.37 (!IRQB), UC7.38 (!IRQA); also elsewhere on the board
!NDAC_IN: UC5.10 (PB0); also elsewhere on the board
!NRFD_IN: UC5.16 (PB6); also elsewhere on the board
!NRFD_OUT: UC5.11 (PB1); also elsewhere on the board
!RES: UC5.34 (!RES), UC7.34 (!RES); also elsewhere on the board
!SELE: UC5.23 (!CS2), UC7.23 (!CS2); also elsewhere on the board
!SRQ_IN: J2.3 (!SRQ); also elsewhere on the board
#1_CASS_MOTOR: J3.3 (MOTOR1), J3.C (MOTOR2), Q4.3 (E)
#1_CASS_READ: J2.8 (READ1), J3.4 (READ1), J3.D (READ2), R101.2, UC7.40 (CA1)
#1_CASS_SWITCH: J3.6 (SENSE1), J3.F (SENSE2), UC7.6 (PA4)
#2_CASS_READ: J2.6 (READ2), R100.2, UC5.18 (CB1)
#2_CASS_SWITCH: SP2.1, UC7.7 (PA5)
+5V: J3.2 (VCC1), J3.B (VCC2), R100.1, R101.1, R102.2, RN1.1, UC5.20 (VCC), UC7.20 (VCC), UC9.16 (VCC); also elsewhere on the board
+9V_UNREG: C70.1, Q4.2 (C), Q5.1 (C), R4.2; also elsewhere on the board
B02: UC5.25 (PHI2), UC7.25 (CLK2); also elsewhere on the board
BA0: UC5.38 (RS0), UC7.36 (RS0); also elsewhere on the board
BA1: UC5.37 (RS1), UC7.35 (RS1); also elsewhere on the board
BA2: UC5.36 (RS2); also elsewhere on the board
BA3: UC5.35 (RS3); also elsewhere on the board
BA4: UC7.24 (CS1); also elsewhere on the board
BA6: UA4.13 (I1); also elsewhere on the board
CA1: J2.B (CA1), R102.1, UC5.40 (CA1)
CASS_WRITE: J2.7 (WRITE), J3.5 (WRITE1), J3.E (WRITE2), UC5.13 (PB3)
CB2: J2.M (CB2), UC5.19 (CB2), UH5.1 (I0)
CS1: UA4.8 (O), UC5.24 (CS1)
D0: UC5.33 (D0), UC7.33 (D0); also elsewhere on the board
D1: UC5.32 (D1), UC7.32 (D1); also elsewhere on the board
D2: UC5.31 (D2), UC7.31 (D2); also elsewhere on the board
D3: UC5.30 (D3), UC7.30 (D3); also elsewhere on the board
D4: UC5.29 (D4), UC7.29 (D4); also elsewhere on the board
D5: UC5.28 (D5), UC7.28 (D5); also elsewhere on the board
D6: UC5.27 (D6), UC7.27 (D6); also elsewhere on the board
D7: UC5.26 (D7), UC7.26 (D7); also elsewhere on the board
DIAG: J2.5 (DIAG), UC7.9 (PA7), UH5.2 (I1)
GND: J2.1 (GND1), J2.12 (GND3), J2.A (GND2), J2.N (GND4), J3.1 (GND1), J3.A (GND2), J5.20 (12), SG1.- (2), UC5.1 (VSS), UC7.1 (VSS), UC9.8 (GND); also elsewhere on the board
GRAPHIC: J2.11 (GRAPH), UC5.39 (CA2); also elsewhere on the board
KEYA: UC7.2 (PA0), UC9.15 (A)
KEYB: UC7.3 (PA1), UC9.14 (B)
KEYC: UC7.4 (PA2), UC9.13 (C)
KEYD: UC7.5 (PA3), UC9.12 (D)
KIN0: J5.1 (A), RN1.2, UC7.10 (PB0)
KIN1: J5.2 (B), RN1.3, UC7.11 (PB1)
KIN2: J5.3 (C), RN1.4, UC7.12 (PB2)
KIN3: J5.4 (D), RN1.5, UC7.13 (PB3)
KIN4: J5.5 (E), RN1.6, UC7.14 (PB4)
KIN5: J5.6 (F), RN1.7, UC7.15 (PB5)
KIN6: J5.7 (H), RN1.8, UC7.16 (PB6)
KIN7: J5.8 (J), RN1.9, UC7.17 (PB7)
unnamed: R9.2, UH5.3 (O)
unnamed: R9.1, SG1.+ (1)
unnamed: J2.2 (VIDEO), VID.1
unnamed: J2.10 (TV-H), TV-H.1
unnamed: J2.9 (TV-V), TV-V.1
unnamed: UA4.9 (I0), UA4.10 (I1), UA4.11 (O)
unnamed: SP1.1, UC5.14 (PB4)
unnamed: Q6.2 (B), R5.2, R6.1
unnamed: Q6.3 (E), R6.2, VR2.A
unnamed: C70.2, Q5.2 (B), Q6.1 (C), R4.1, VR2.C
unnamed: Q4.1 (B), Q5.3 (E)
unnamed: R5.1, UC7.19 (CB2)
unnamed: J5.18 (10), UC9.11 (9)
unnamed: J5.17 (9), UC9.10 (8)
unnamed: J5.16 (8), UC9.9 (7)
unnamed: J5.15 (7), UC9.7 (6)
unnamed: J5.14 (6), UC9.6 (5)
unnamed: J5.13 (5), UC9.5 (4)
unnamed: J5.12 (4), UC9.4 (3)
unnamed: J5.11 (3), UC9.3 (2)
unnamed: J5.10 (2), UC9.2 (1)
unnamed: J5.9 (1), UC9.1 (0)
PA0: J2.C (PA0), UC5.2 (PA0)
PA1: J2.D (PA1), UC5.3 (PA1)
PA2: J2.E (PA2), UC5.4 (PA2)
PA3: J2.F (PA3), UC5.5 (PA3)
PA4: J2.H (PA4), UC5.6 (PA4)
PA5: J2.J (PA5), UC5.7 (PA5)
PA6: J2.K (PA6), UC5.8 (PA6)
PA7: J2.L (PA7), UC5.9 (PA7)
R/!W: UC5.22 (R/!W), UC7.21 (R/!W); also elsewhere on the board
VIDEO_ON: UC5.15 (PB5), UC7.18 (CB1); also elsewhere on the board
X8XX: UA4.12 (I0), UC7.22 (CS0); also elsewhere on the board

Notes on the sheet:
LOGIC DIAGRAM - DYNAMIC PET
CASSETTE & KEYBOARD
MTI

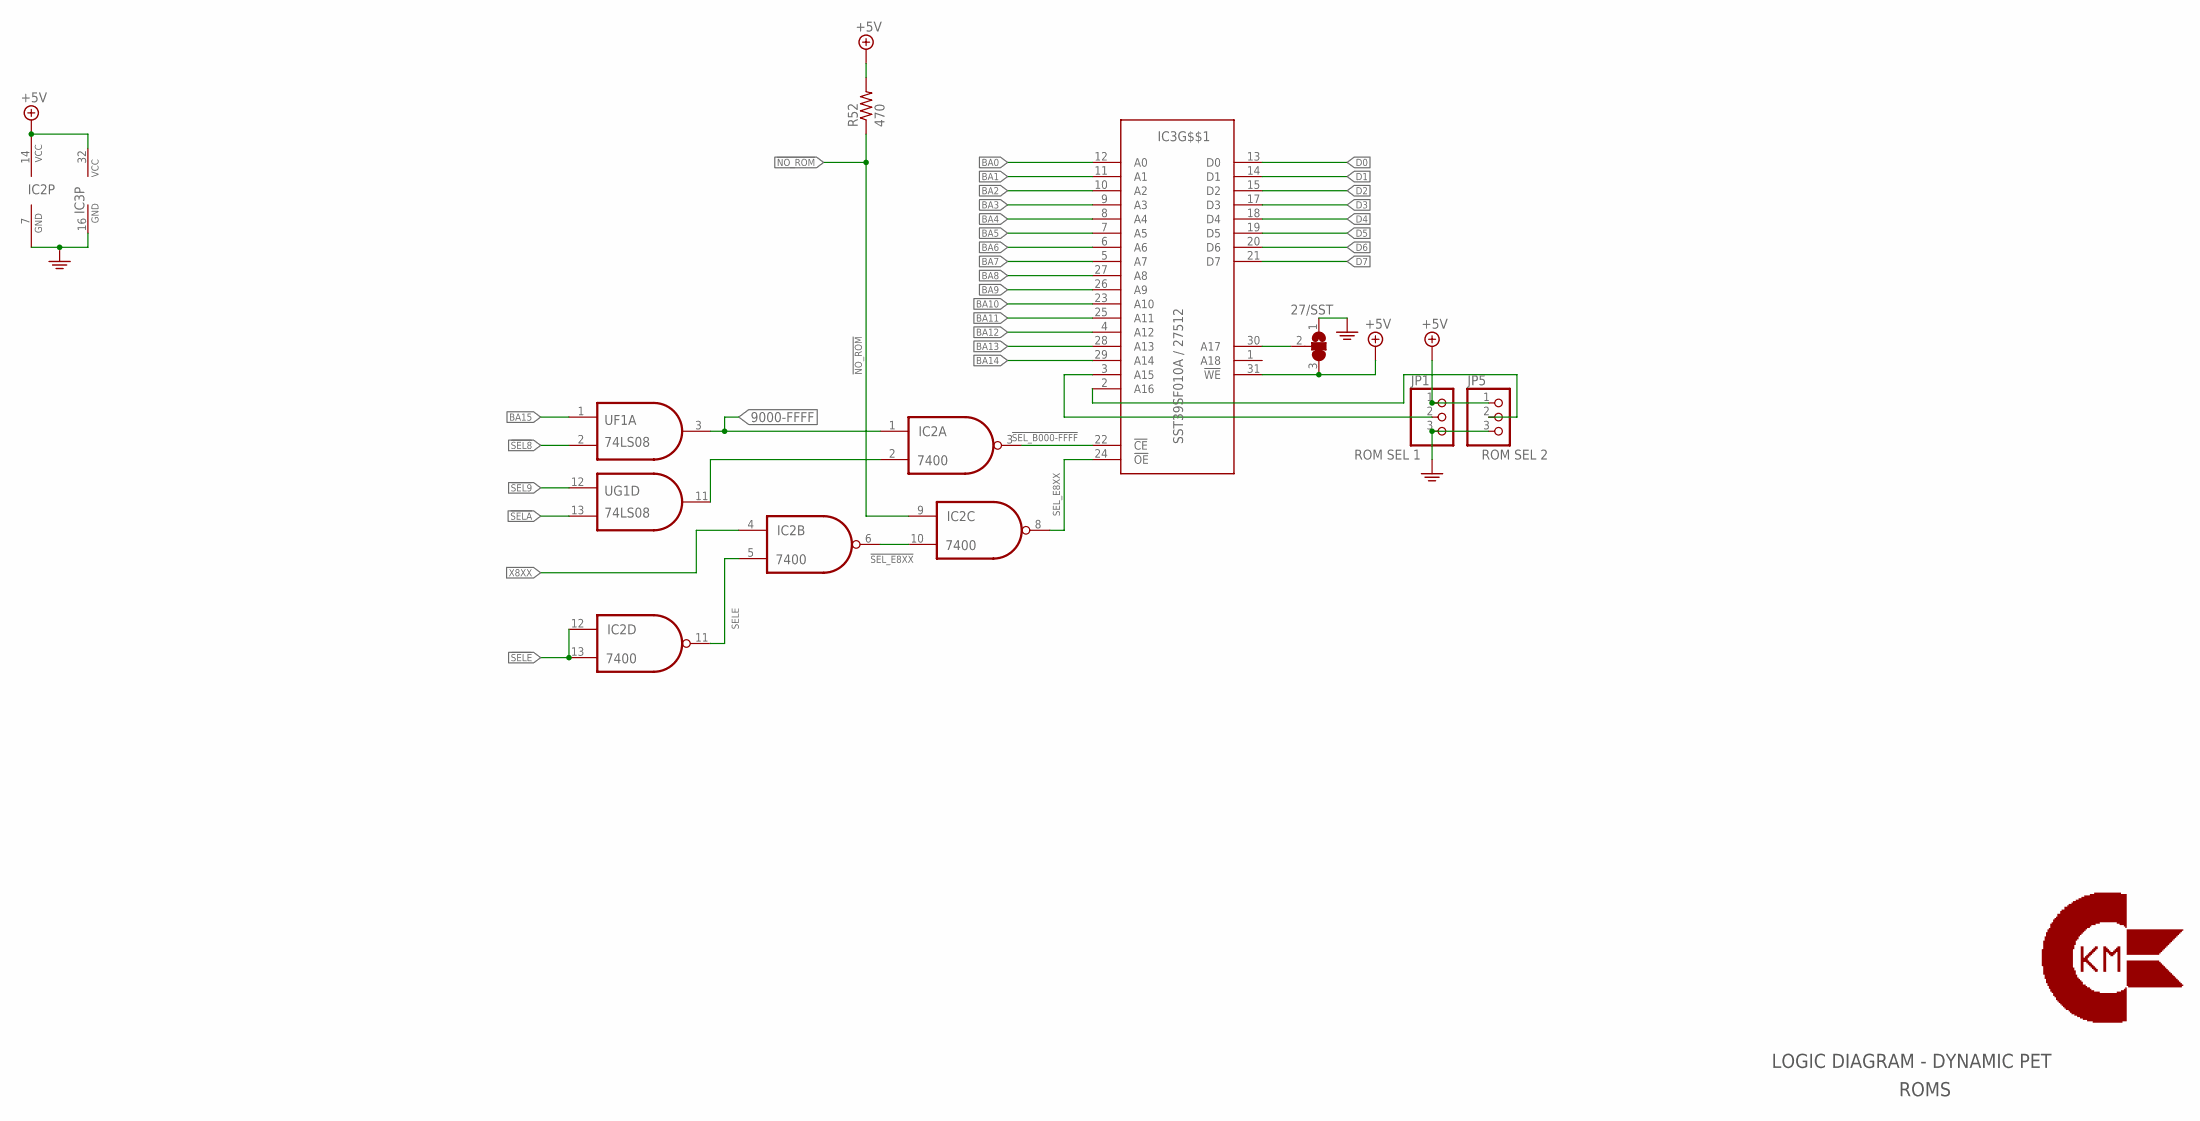
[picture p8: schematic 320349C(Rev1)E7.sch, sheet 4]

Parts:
27/SST: 27/SST; SJ_2
IC2: 7400; DIL14
IC3: SST39SF010A / 27512; SST39SF010A
JP1: ROM SEL 1; 1X03
JP5: ROM SEL 2; 1X03
R52: 470; 0207/10
UF1: 74LS08; DIL14
UG1: 74LS08; DIL14

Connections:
9000-FFFF: IC2.1 (I0), UF1.3 (O); also elsewhere on the board
!NO_ROM: IC2.9 (I0), R52.1; also elsewhere on the board
!SEL8: UF1.2 (I1); also elsewhere on the board
!SEL9: UG1.12 (I0); also elsewhere on the board
!SELA: UG1.13 (I1); also elsewhere on the board
!SELE: IC2.12 (I0), IC2.13 (I1); also elsewhere on the board
!SEL_B000-FFFF: IC2.3 (O), IC3.22 (!CE)
!SEL_E8XX: IC2.6 (O), IC2.10 (I1); also elsewhere on the board
+5V: 27/SST.3, IC2.14 (VCC), IC3.31 (!WE), IC3.32 (VCC), JP1.1, JP5.1, R52.2; also elsewhere on the board
BA0: IC3.12 (A0); also elsewhere on the board
BA1: IC3.11 (A1); also elsewhere on the board
BA2: IC3.10 (A2); also elsewhere on the board
BA3: IC3.9 (A3); also elsewhere on the board
BA4: IC3.8 (A4); also elsewhere on the board
BA5: IC3.7 (A5); also elsewhere on the board
BA6: IC3.6 (A6); also elsewhere on the board
BA7: IC3.5 (A7); also elsewhere on the board
BA8: IC3.27 (A8); also elsewhere on the board
BA9: IC3.26 (A9); also elsewhere on the board
BA10: IC3.23 (A10); also elsewhere on the board
BA11: IC3.25 (A11); also elsewhere on the board
BA12: IC3.4 (A12); also elsewhere on the board
BA13: IC3.28 (A13); also elsewhere on the board
BA14: IC3.29 (A14); also elsewhere on the board
BA15: UF1.1 (I0); also elsewhere on the board
D0: IC3.13 (D0); also elsewhere on the board
D1: IC3.14 (D1); also elsewhere on the board
D2: IC3.15 (D2); also elsewhere on the board
D3: IC3.17 (D3); also elsewhere on the board
D4: IC3.18 (D4); also elsewhere on the board
D5: IC3.19 (D5); also elsewhere on the board
D6: IC3.20 (D6); also elsewhere on the board
D7: IC3.21 (D7); also elsewhere on the board
GND: 27/SST.1, IC2.7 (GND), IC3.16 (GND), JP1.3, JP5.3; also elsewhere on the board
unnamed: IC2.2 (I1), UG1.11 (O)
unnamed: IC3.3 (A15), JP1.2
unnamed: IC3.2 (A16), JP5.2
unnamed: 27/SST.2, IC3.30 (A17)
SELE: IC2.5 (I1), IC2.11 (O)
SEL_E8XX: IC2.8 (O), IC3.24 (!OE)
X8XX: IC2.4 (I0); also elsewhere on the board

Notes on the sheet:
LOGIC DIAGRAM - DYNAMIC PET
ROMS

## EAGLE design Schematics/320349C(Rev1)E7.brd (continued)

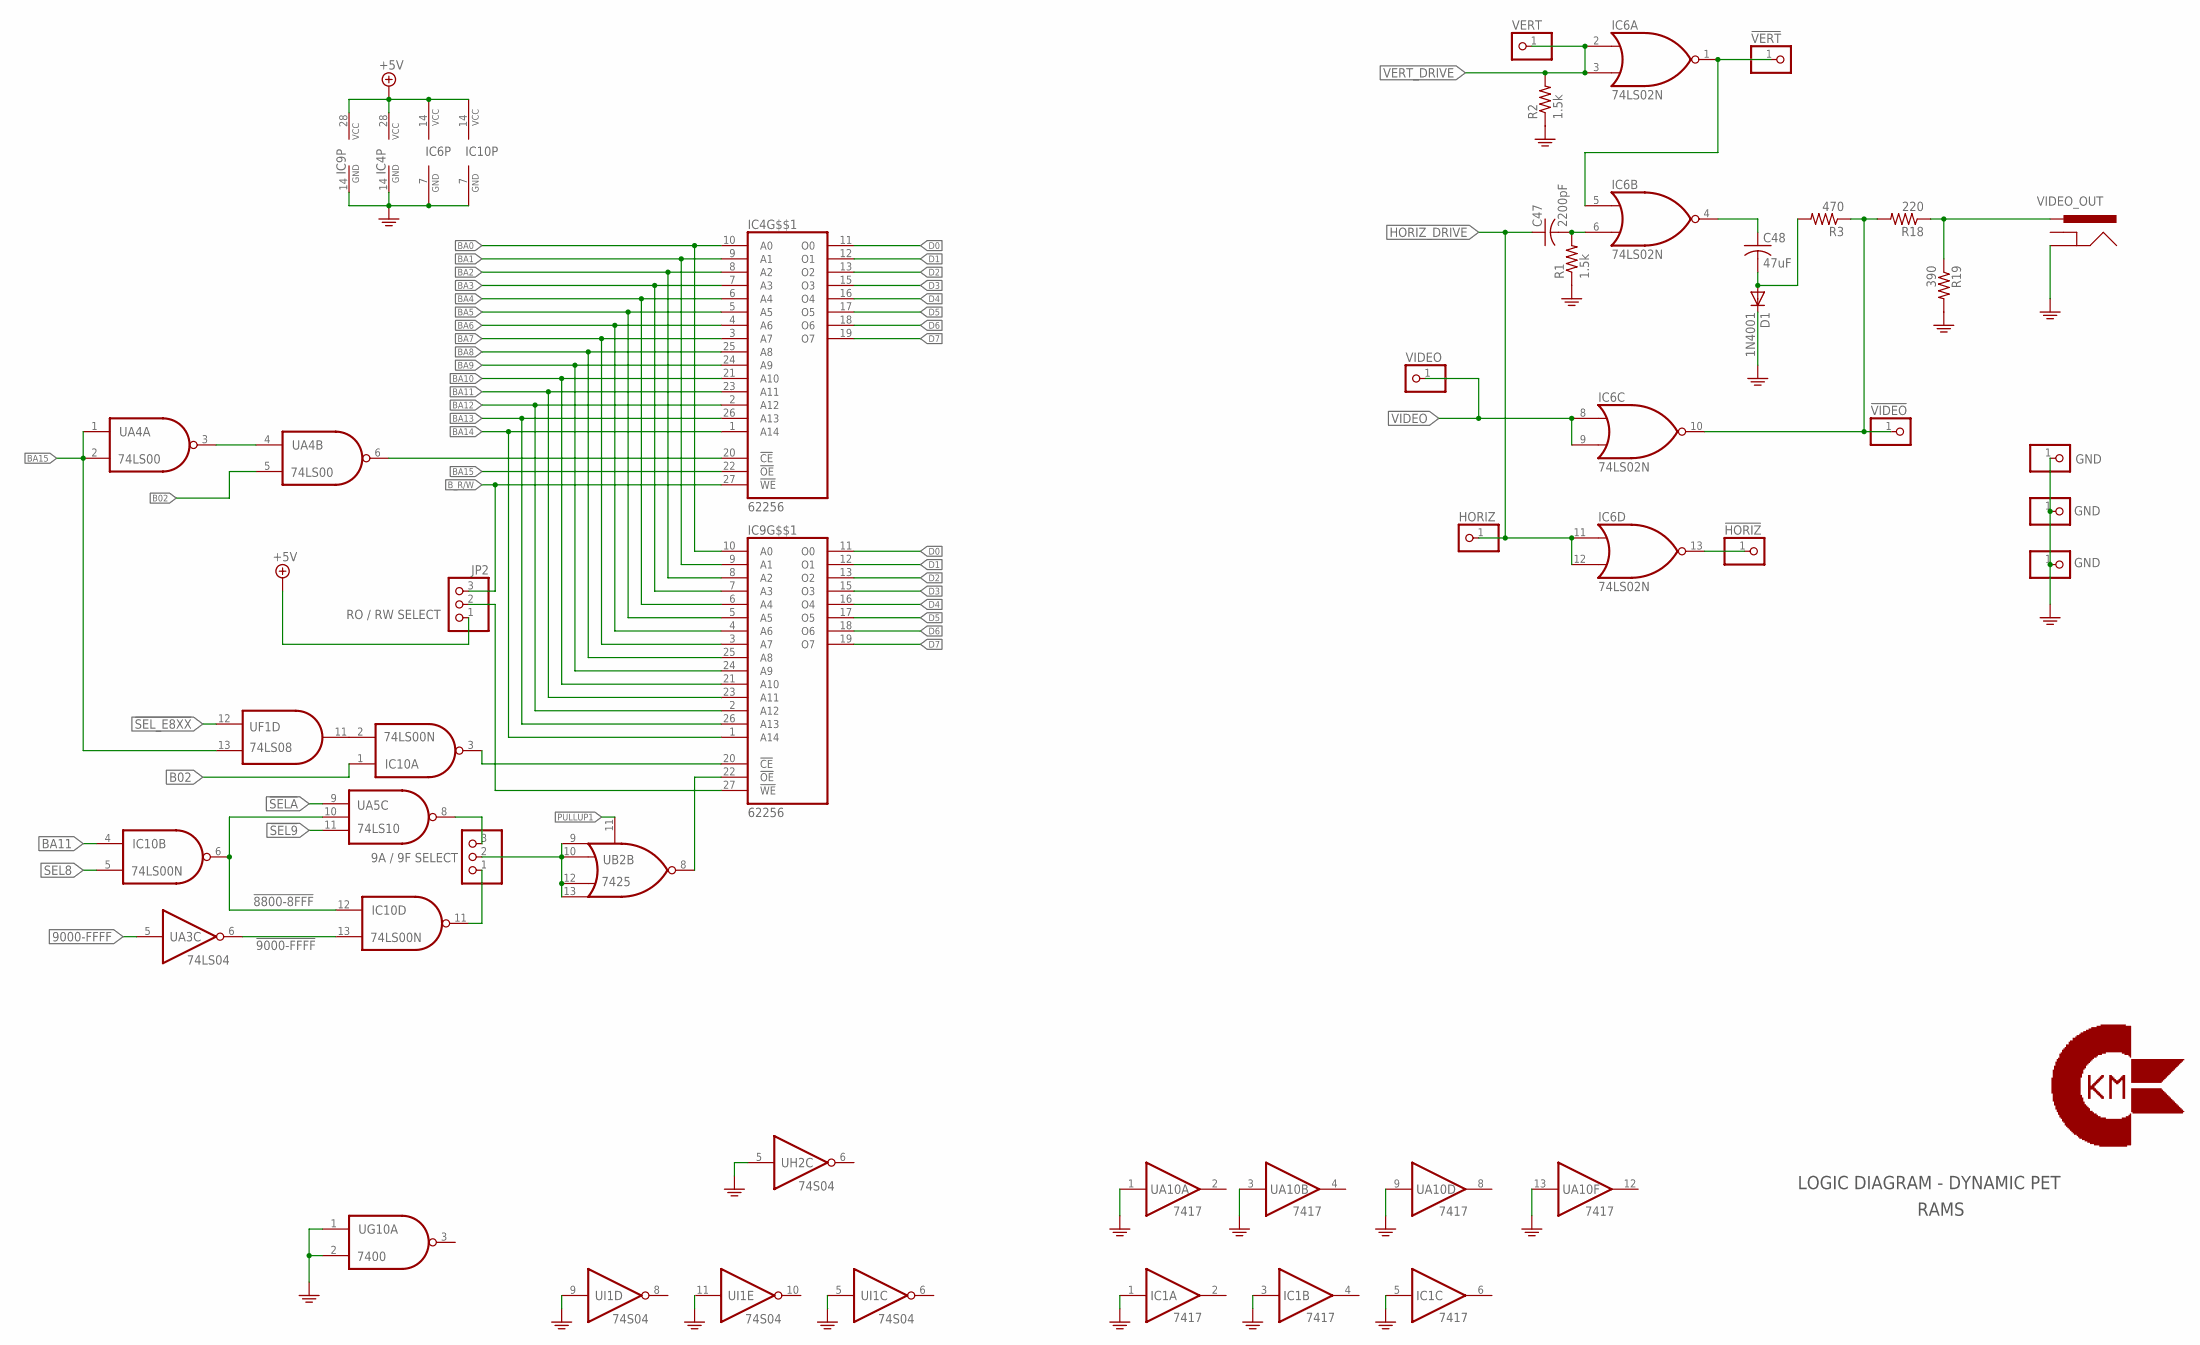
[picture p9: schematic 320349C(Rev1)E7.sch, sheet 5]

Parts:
!HORIZ: PINHD-1X1; 1X01
!VERT: PINHD-1X1; 1X01
!VIDEO: PINHD-1X1; 1X01
C47: 2200pF; C025-025X050
C48: 47uF; C050-035X075
D1: 1N4001; DO41-10
HGND: GND; 1X01
HORIZ: PINHD-1X1; 1X01
IC1: 7417; DIL14
IC4, IC9: 62256; DIL28
IC6: 74LS02N; DIL14
IC10: 74LS00N; DIL14
JP2: RO / RW SELECT; 1X03
JP3: 9A / 9F SELECT; 1X03
R1, R2: 1.5k; 0207/10
R3: 470; 0207/10
R18: 220; 0207/10
R19: 390; 0207/10
UA3: 74LS04; DIL14
UA4: 74LS00; DIL14
UA5: 74LS10; DIL14
UA10: 7417; DIL14
UB2: 7425; DIL14
UF1: 74LS08; DIL14
UG10: 7400; DIL14
UH2: 74S04; DIL14
UI1: 74S04; DIL14
VDGND: GND; 1X01
VERT: PINHD-1X1; 1X01
VGND: GND; 1X01
VIDEO: PINHD-1X1; 1X01
VIDEO_OUT: POWER_JACKRCA; RCA

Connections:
9000-FFFF: UA3.5 (I); also elsewhere on the board
!8800-8FFF: IC10.6 (O), IC10.12 (I0), UA5.10 (I1)
!9000-FFFF: IC10.13 (I1), UA3.6 (O)
!SEL9: UA5.11 (I2); also elsewhere on the board
!SELA: UA5.9 (I0); also elsewhere on the board
!SEL_E8XX: UF1.12 (I0); also elsewhere on the board
+5V: IC4.28 (VCC), IC6.14 (VCC), IC9.28 (VCC), IC10.14 (VCC), JP2.1; also elsewhere on the board
B02: IC10.1 (I0), UA4.5 (I1); also elsewhere on the board
BA0: IC4.10 (A0), IC9.10 (A0); also elsewhere on the board
BA1: IC4.9 (A1), IC9.9 (A1); also elsewhere on the board
BA2: IC4.8 (A2), IC9.8 (A2); also elsewhere on the board
BA3: IC4.7 (A3), IC9.7 (A3); also elsewhere on the board
BA4: IC4.6 (A4), IC9.6 (A4); also elsewhere on the board
BA5: IC4.5 (A5), IC9.5 (A5); also elsewhere on the board
BA6: IC4.4 (A6), IC9.4 (A6); also elsewhere on the board
BA7: IC4.3 (A7), IC9.3 (A7); also elsewhere on the board
BA8: IC4.25 (A8), IC9.25 (A8); also elsewhere on the board
BA9: IC4.24 (A9), IC9.24 (A9); also elsewhere on the board
BA10: IC4.21 (A10), IC9.21 (A10); also elsewhere on the board
BA11: IC4.23 (A11), IC9.23 (A11), IC10.4 (I0); also elsewhere on the board
BA12: IC4.2 (A12), IC9.2 (A12); also elsewhere on the board
BA13: IC4.26 (A13), IC9.26 (A13); also elsewhere on the board
BA14: IC4.1 (A14), IC9.1 (A14); also elsewhere on the board
BA15: IC4.22 (!OE), UA4.1 (I0), UA4.2 (I1), UF1.13 (I1); also elsewhere on the board
B_R/W: IC4.27 (!WE), JP2.3; also elsewhere on the board
D0: IC4.11 (O0), IC9.11 (O0); also elsewhere on the board
D1: IC4.12 (O1), IC9.12 (O1); also elsewhere on the board
D2: IC4.13 (O2), IC9.13 (O2); also elsewhere on the board
D3: IC4.15 (O3), IC9.15 (O3); also elsewhere on the board
D4: IC4.16 (O4), IC9.16 (O4); also elsewhere on the board
D5: IC4.17 (O5), IC9.17 (O5); also elsewhere on the board
D6: IC4.18 (O6), IC9.18 (O6); also elsewhere on the board
D7: IC4.19 (O7), IC9.19 (O7); also elsewhere on the board
GND: D1.C, HGND.1, IC1.1 (I), IC1.3 (I), IC1.5 (I), IC4.14 (GND), IC6.7 (GND), IC9.14 (GND), IC10.7 (GND), R1.1, R2.1, R19.2, UA10.1 (I), UA10.3 (I), UA10.9 (I), UA10.13 (I), UG10.1 (I0), UG10.2 (I1), UH2.5 (I), UI1.5 (I), UI1.9 (I), UI1.11 (I), VDGND.1, VGND.1, VIDEO_OUT.BARREL (GND); also elsewhere on the board
HORIZ_DRIVE: C47.1, HORIZ.1, IC6.11 (I0), IC6.12 (I1); also elsewhere on the board
unnamed: JP3.3, UA5.8 (O)
unnamed: !VERT.1, IC6.1 (O), IC6.5 (I0)
unnamed: IC10.2 (I1), UF1.11 (O)
unnamed: R18.1, R19.1, VIDEO_OUT.BREAK (PWR)
unnamed: C47.2, IC6.6 (I1), R1.2
unnamed: IC9.22 (!OE), UB2.8 (O)
unnamed: !VIDEO.1, IC6.10 (O), R3.1, R18.2
unnamed: JP3.2, UB2.9 (I0), UB2.10 (I1), UB2.12 (I2), UB2.13 (I3)
unnamed: C48.1, IC6.4 (O)
unnamed: C48.2, D1.A, R3.2
unnamed: IC9.20 (!CE), IC10.3 (O)
unnamed: IC9.27 (!WE), JP2.2
unnamed: !HORIZ.1, IC6.13 (O)
unnamed: IC4.20 (!CE), UA4.6 (O)
unnamed: IC10.11 (O), JP3.1
unnamed: UA4.3 (O), UA4.4 (I0)
PULLUP1: UB2.11 (G); also elsewhere on the board
SEL8: IC10.5 (I1); also elsewhere on the board
VERT_DRIVE: IC6.2 (I0), IC6.3 (I1), R2.2, VERT.1; also elsewhere on the board
VIDEO: IC6.8 (I0), IC6.9 (I1), VIDEO.1; also elsewhere on the board

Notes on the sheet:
LOGIC DIAGRAM - DYNAMIC PET
RAMS

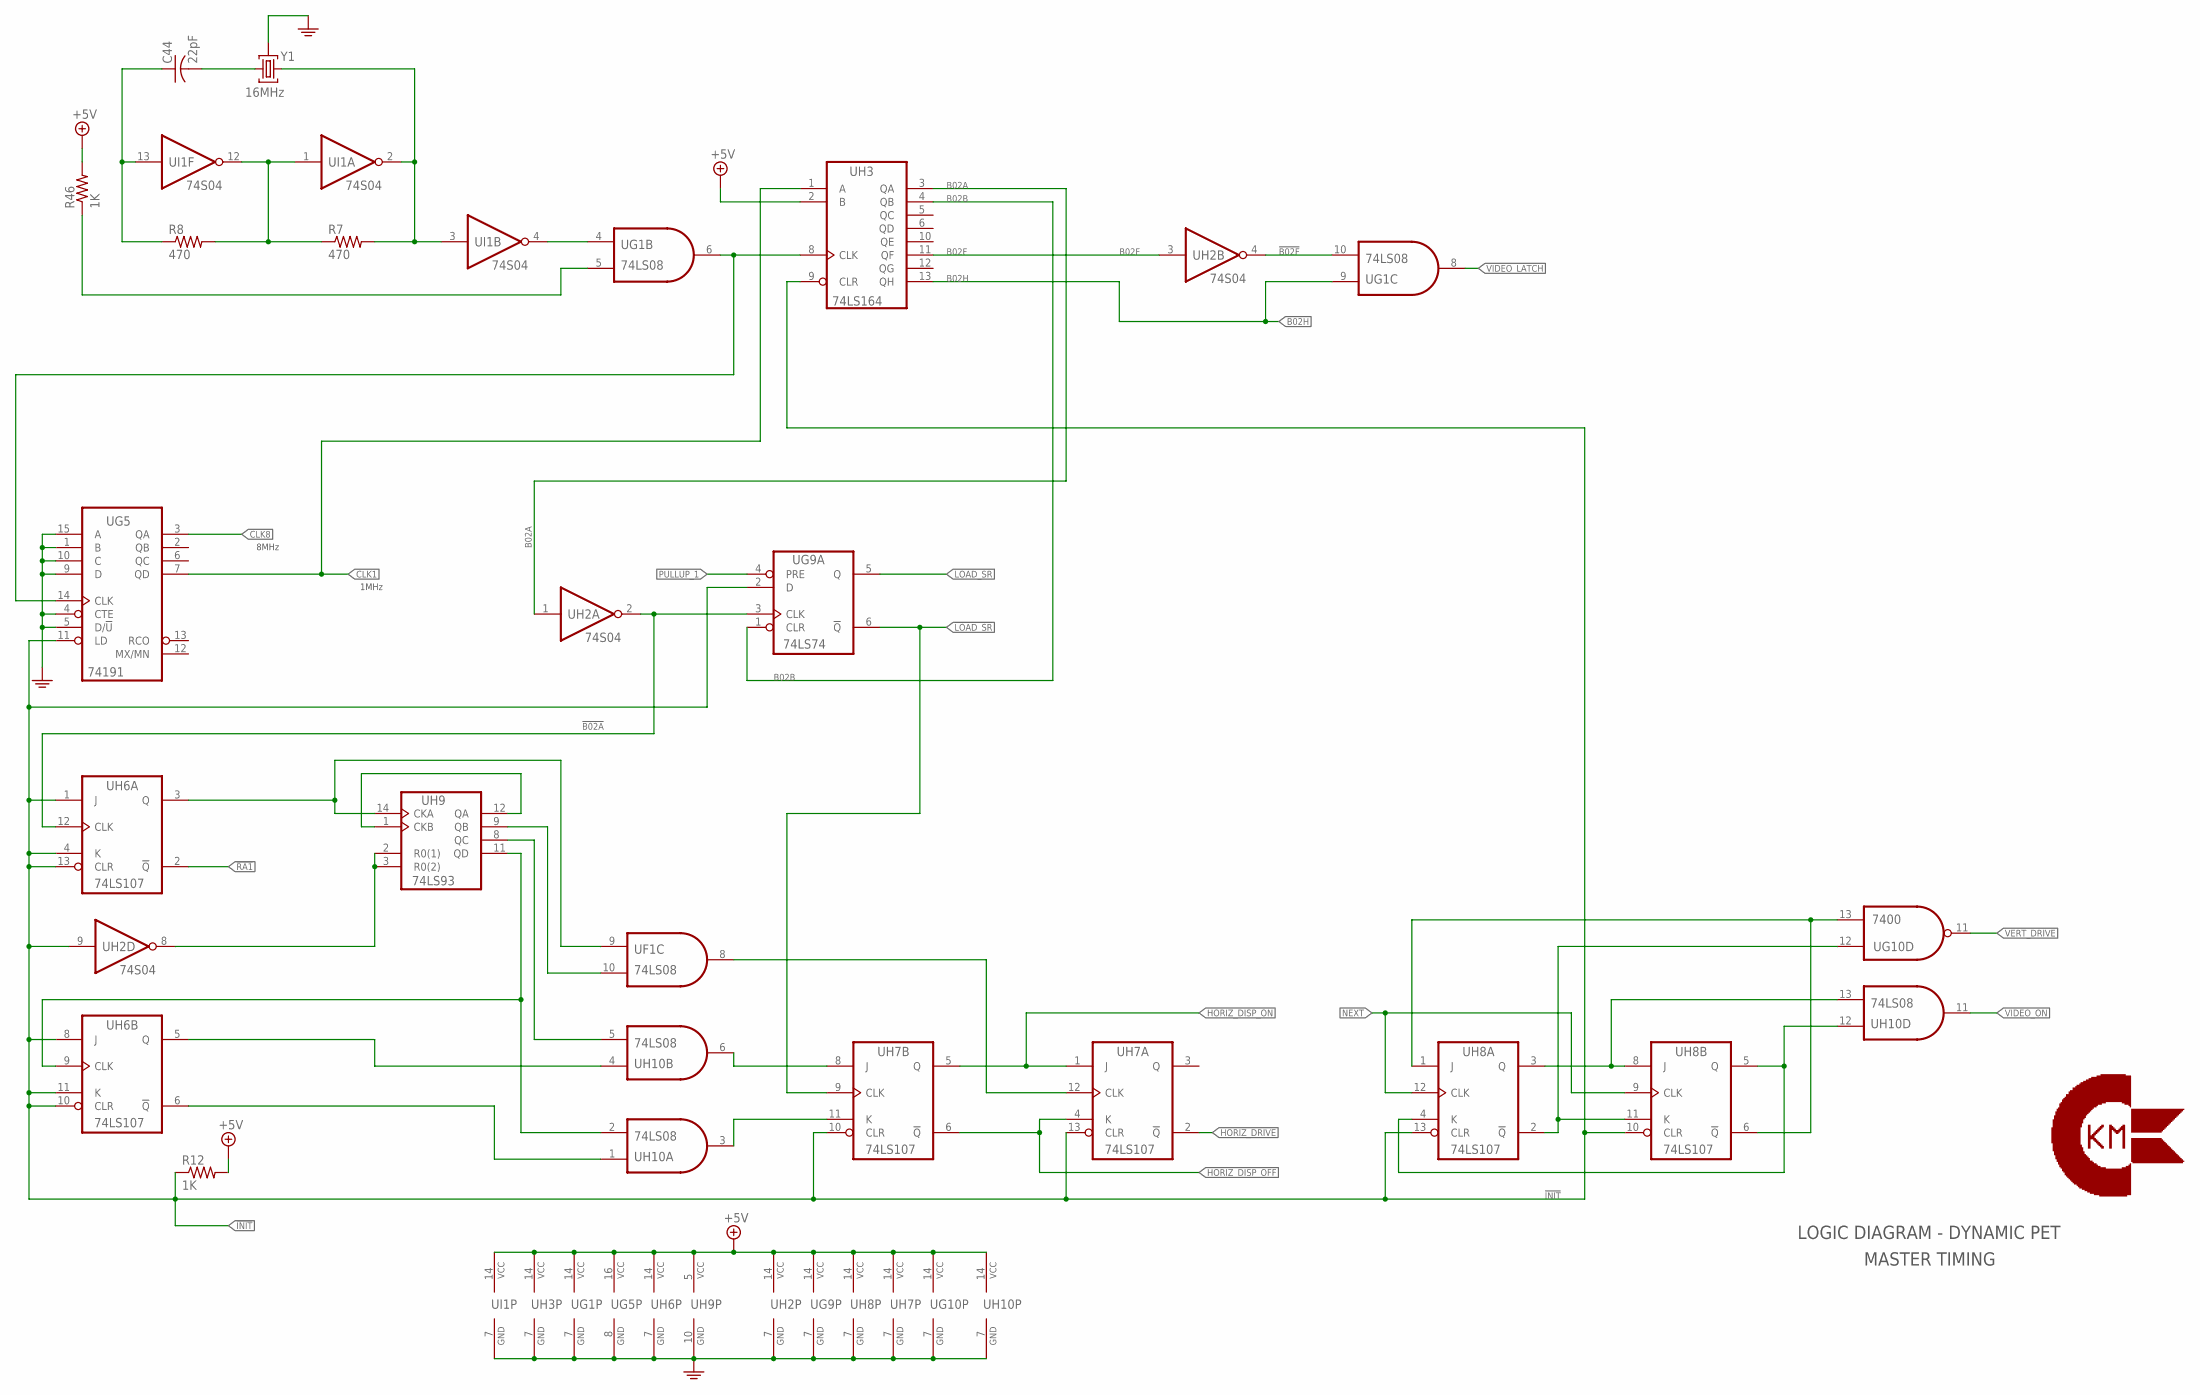
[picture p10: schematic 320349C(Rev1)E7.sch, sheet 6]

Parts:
C44: 22pF; C050-035X075
R7, R8: 470; 0207/10
R12, R46: 1K; 0207/10
UF1: 74LS08; DIL14
UG1: 74LS08; DIL14
UG5: 74191; DIL16
UG9: 74LS74; DIL14
UG10: 7400; DIL14
UH2: 74S04; DIL14
UH3: 74LS164; DIL14
UH6, UH7, UH8: 74LS107; DIL14
UH9: 74LS93; DIL14
UH10: 74LS08; DIL14
UI1: 74S04; DIL14
Y1: 16MHz; HC49TL-H

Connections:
!B02A: UG9.3 (CLK), UH2.2 (O), UH6.12 (CLK)
!B02F: UG1.10 (I1), UH2.4 (O)
!INIT: R12.1, UG5.11 (LD), UG9.2 (D), UH2.9 (I), UH3.9 (CLR), UH6.1 (J), UH6.4 (K), UH6.8 (J), UH6.10 (CLR), UH6.11 (K), UH6.13 (CLR), UH7.10 (CLR), UH7.13 (CLR), UH8.10 (CLR), UH8.13 (CLR); also elsewhere on the board
!LOAD_SR: UG9.6 (!Q), UH7.9 (CLK); also elsewhere on the board
!RA1: UH6.2 (!Q); also elsewhere on the board
+5V: R12.2, R46.2, UG1.14 (VCC), UG5.16 (VCC), UG9.14 (VCC), UG10.14 (VCC), UH2.14 (VCC), UH3.2 (B), UH3.14 (VCC), UH6.14 (VCC), UH7.14 (VCC), UH8.14 (VCC), UH9.5 (VCC), UH10.14 (VCC), UI1.14 (VCC); also elsewhere on the board
B02A: UH2.1 (I), UH3.3 (QA)
B02B: UG9.1 (CLR), UH3.4 (QB)
B02F: UH2.3 (I), UH3.11 (QF)
B02H: UG1.9 (I0), UH3.13 (QH); also elsewhere on the board
CLK1: UG5.7 (QD), UH3.1 (A); also elsewhere on the board
CLK8: UG5.3 (QA); also elsewhere on the board
GND: UG1.7 (GND), UG5.1 (B), UG5.4 (CTE), UG5.5 (D/!U), UG5.8 (GND), UG5.9 (D), UG5.10 (C), UG5.15 (A), UG9.7 (GND), UG10.7 (GND), UH2.7 (GND), UH3.7 (GND), UH6.7 (GND), UH7.7 (GND), UH8.7 (GND), UH9.10 (GND), UH10.7 (GND), UI1.7 (GND), Y1.3; also elsewhere on the board
HORIZ_DISP_OFF: UH7.4 (K), UH7.6 (!Q); also elsewhere on the board
HORIZ_DISP_ON: UH7.1 (J), UH7.5 (Q); also elsewhere on the board
HORIZ_DRIVE: UH7.2 (!Q); also elsewhere on the board
LOAD_SR: UG9.5 (Q); also elsewhere on the board
unnamed: C44.2, Y1.2
unnamed: C44.1, R8.1, UI1.13 (I)
unnamed: UG1.6 (O), UG5.14 (CLK), UH3.8 (CLK)
unnamed: R7.2, UI1.2 (O), UI1.3 (I), Y1.1
unnamed: UG1.4 (I0), UI1.4 (O)
unnamed: UH6.6 (!Q), UH10.1 (I0)
unnamed: UF1.8 (O), UH7.12 (CLK)
unnamed: UH2.8 (O), UH9.2 (R0(1)), UH9.3 (R0(2))
unnamed: UH7.11 (K), UH10.3 (O)
unnamed: UH7.8 (J), UH10.6 (O)
unnamed: UH8.3 (Q), UH8.8 (J), UH10.13 (I1)
unnamed: UG10.12 (I0), UH8.2 (!Q), UH8.11 (K)
unnamed: UH8.4 (K), UH8.5 (Q), UH10.12 (I0)
unnamed: UG10.13 (I1), UH8.1 (J), UH8.6 (!Q)
NEXT: UH8.9 (CLK), UH8.12 (CLK); also elsewhere on the board
PULLUP_1: UG9.4 (PRE); also elsewhere on the board
RA1: UF1.9 (I0), UH6.3 (Q), UH9.14 (CKA)
RA2: UH9.1 (CKB), UH9.12 (QA)
RA3: UF1.10 (I1), UH9.9 (QB)
RA4: UH9.8 (QC), UH10.5 (I1)
RA5: UH6.9 (CLK), UH9.11 (QD), UH10.2 (I1)
RA6: UH6.5 (Q), UH10.4 (I0)
TP8: R46.1, UG1.5 (I1)
TP9: R7.1, R8.2, UI1.1 (I), UI1.12 (O)
VERT_DRIVE: UG10.11 (O); also elsewhere on the board
VIDEO_LATCH: UG1.8 (O); also elsewhere on the board
VIDEO_ON: UH10.11 (O); also elsewhere on the board

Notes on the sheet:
LOGIC DIAGRAM - DYNAMIC PET
MASTER TIMING
8MHz
1MHz

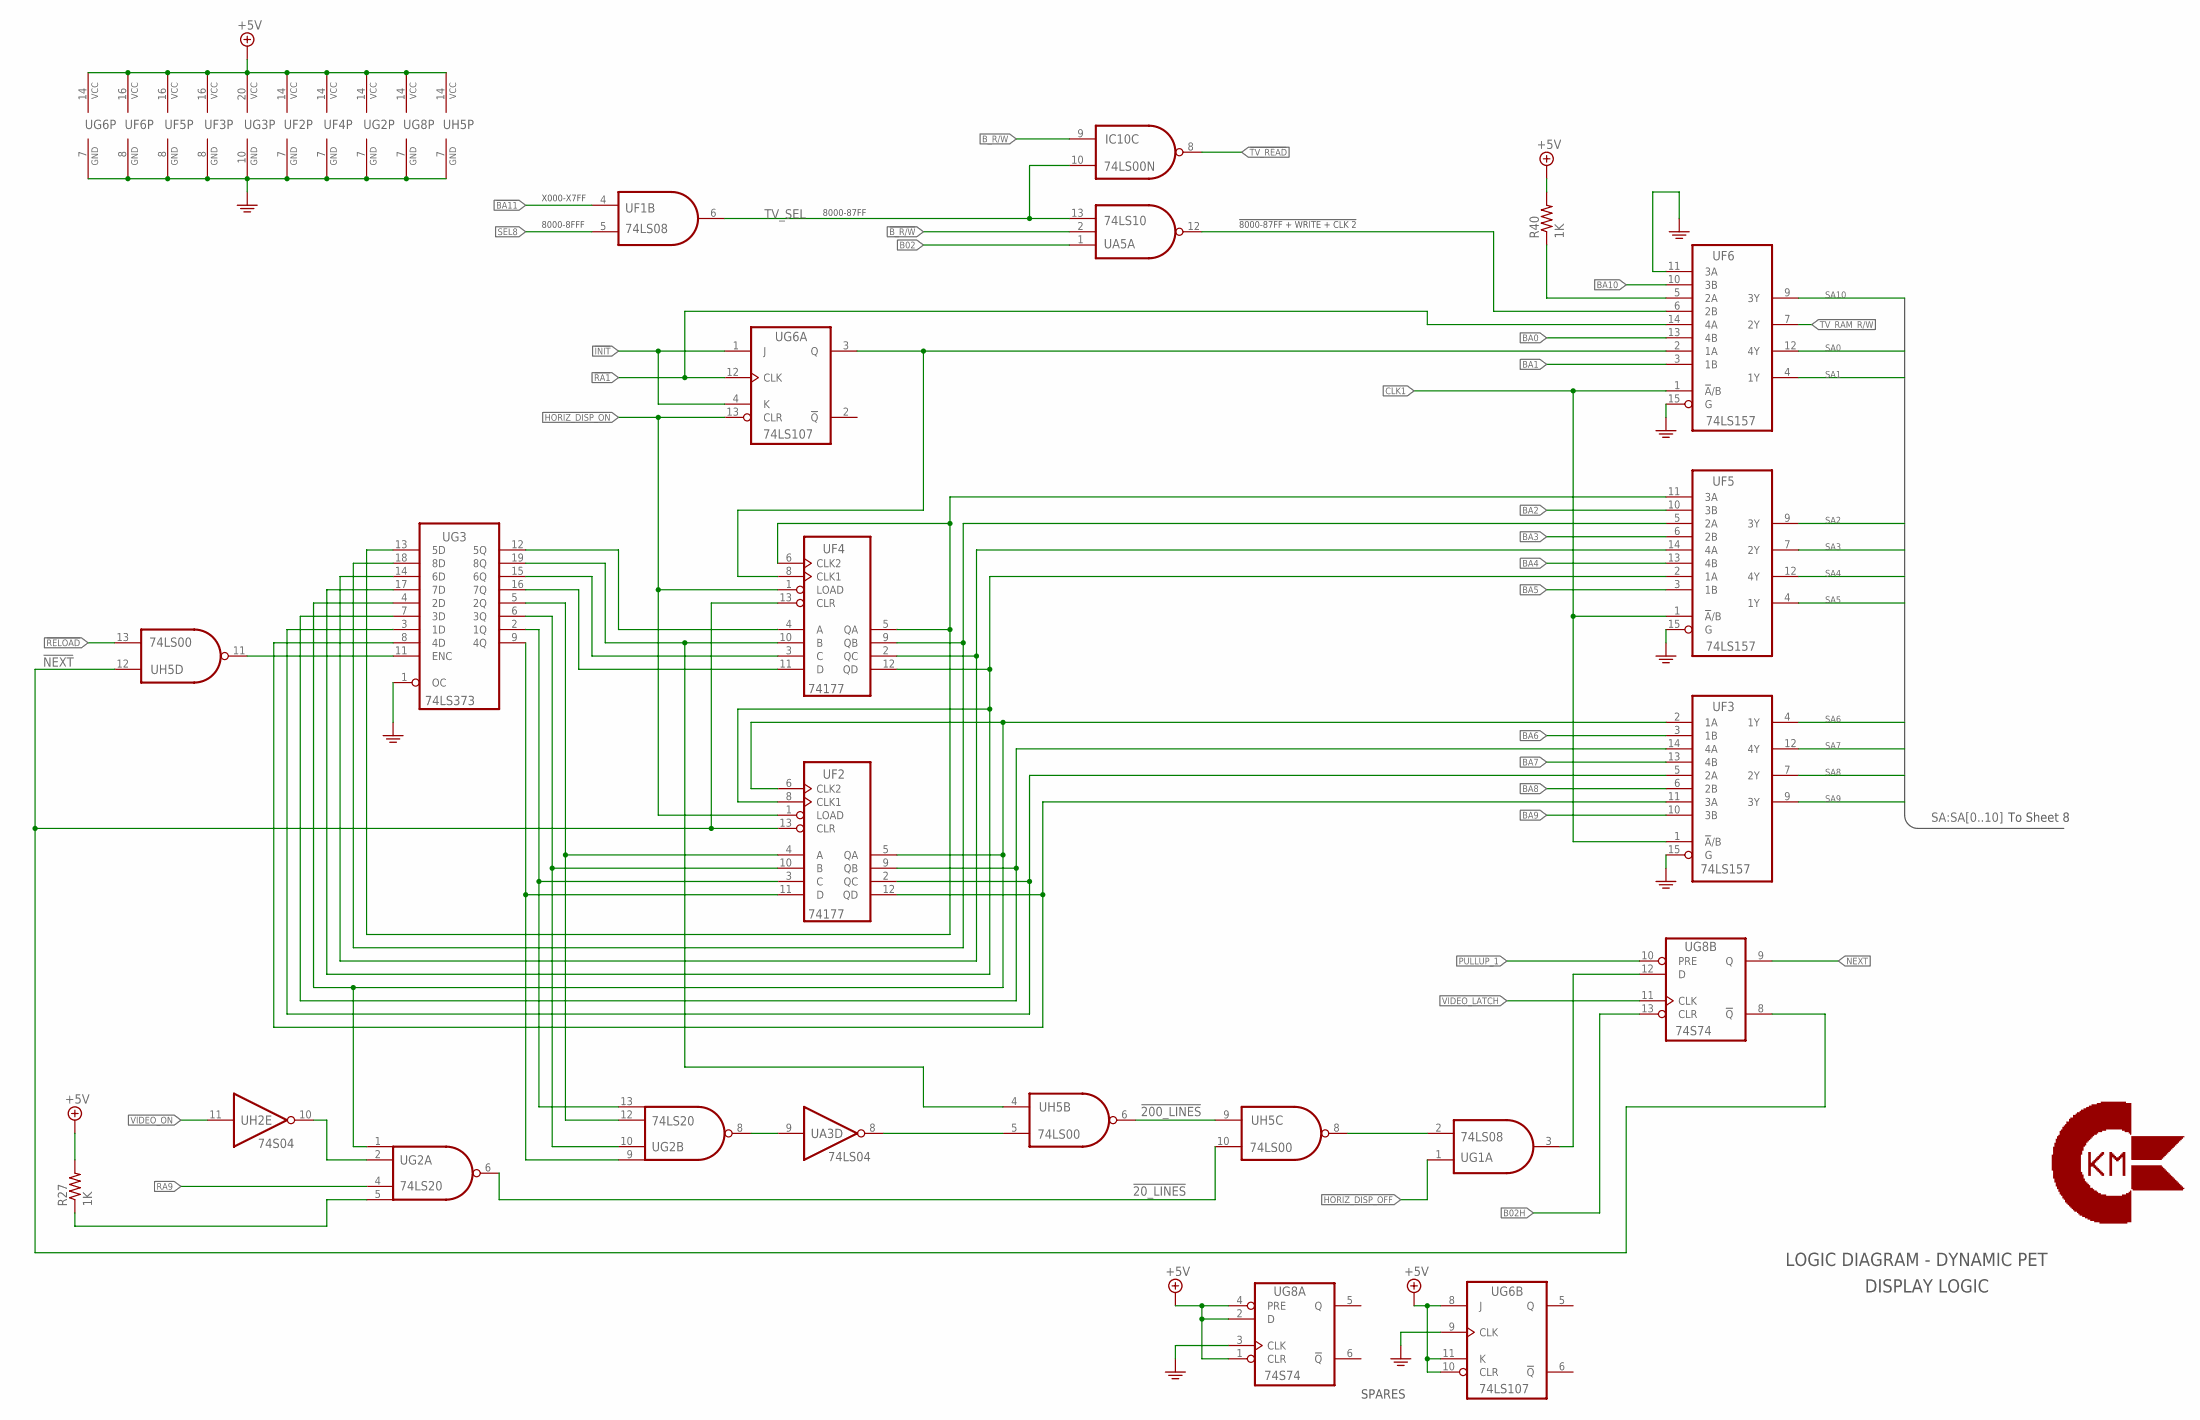
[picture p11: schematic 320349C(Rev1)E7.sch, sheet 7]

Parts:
IC10: 74LS00N; DIL14
R27, R40: 1K; 0207/10
UA3: 74LS04; DIL14
UA5: 74LS10; DIL14
UF1: 74LS08; DIL14
UF2, UF4: 74177; DIL14
UF3, UF5, UF6: 74LS157; DIL16
UG1: 74LS08; DIL14
UG2: 74LS20; DIL14
UG3: 74LS373; DIL20
UG6: 74LS107; DIL14
UG8: 74S74; DIL14
UH2: 74S04; DIL14
UH5: 74LS00; DIL14

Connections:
!20_LINES: UG2.6 (O), UH5.10 (I1)
!200_LINES: UH5.6 (O), UH5.9 (I0)
!BA11: UF1.4 (I0); also elsewhere on the board
!B_R/W: UA5.2 (I1); also elsewhere on the board
!INIT: UG6.1 (J), UG6.4 (K); also elsewhere on the board
!NEXT: UF2.13 (CLR), UF4.13 (CLR), UG8.8 (!Q), UH5.12 (I0)
!RA1: UF6.14 (4A), UG6.12 (CLK); also elsewhere on the board
!RELOAD: UH5.13 (I1); also elsewhere on the board
!TV_READ: IC10.8 (O); also elsewhere on the board
+5V: R27.2, R40.2, UF2.14 (VCC), UF3.16 (VCC), UF4.14 (VCC), UF5.16 (VCC), UF6.16 (VCC), UG2.14 (VCC), UG3.20 (VCC), UG6.8 (J), UG6.10 (CLR), UG6.11 (K), UG6.14 (VCC), UG8.1 (CLR), UG8.2 (D), UG8.4 (PRE), UG8.14 (VCC), UH5.14 (VCC); also elsewhere on the board
B02: UA5.1 (I0); also elsewhere on the board
B02H: UG8.13 (CLR); also elsewhere on the board
BA0: UF6.13 (4B); also elsewhere on the board
BA1: UF6.3 (1B); also elsewhere on the board
BA2: UF5.10 (3B); also elsewhere on the board
BA3: UF5.6 (2B); also elsewhere on the board
BA4: UF5.13 (4B); also elsewhere on the board
BA5: UF5.3 (1B); also elsewhere on the board
BA6: UF3.3 (1B); also elsewhere on the board
BA7: UF3.13 (4B); also elsewhere on the board
BA8: UF3.6 (2B); also elsewhere on the board
BA9: UF3.10 (3B); also elsewhere on the board
BA10: UF6.10 (3B); also elsewhere on the board
B_R/W: IC10.9 (I0); also elsewhere on the board
CLK1: UF3.1 (!A!/B), UF5.1 (!A!/B), UF6.1 (!A!/B); also elsewhere on the board
GND: UF2.7 (GND), UF3.8 (GND), UF3.15 (G), UF4.7 (GND), UF5.8 (GND), UF5.15 (G), UF6.8 (GND), UF6.11 (3A), UF6.15 (G), UG2.7 (GND), UG3.1 (OC), UG3.10 (GND), UG6.7 (GND), UG6.9 (CLK), UG8.3 (CLK), UG8.7 (GND), UH5.7 (GND); also elsewhere on the board
HORIZ_DISP_OFF: UG1.1 (I0); also elsewhere on the board
HORIZ_DISP_ON: UF2.1 (LOAD), UF4.1 (LOAD), UG6.13 (CLR); also elsewhere on the board
unnamed: UF4.5 (QA), UF4.6 (CLK2), UF5.11 (3A), UG3.13 (5D)
unnamed: UF4.9 (QB), UF5.5 (2A), UG3.18 (8D)
unnamed: UF4.2 (QC), UF5.14 (4A), UG3.14 (6D)
unnamed: UF2.8 (CLK1), UF4.12 (QD), UF5.2 (1A), UG3.17 (7D)
unnamed: UF2.5 (QA), UF2.6 (CLK2), UF3.2 (1A), UG2.1 (I0), UG3.4 (2D)
unnamed: UF2.9 (QB), UF3.14 (4A), UG3.7 (3D)
unnamed: R40.1, UF6.5 (2A)
unnamed: UA5.12 (O), UF6.6 (2B)
unnamed: UF4.8 (CLK1), UF6.2 (1A), UG6.3 (Q)
unnamed: UF2.2 (QC), UF3.5 (2A), UG3.3 (1D)
unnamed: UF2.12 (QD), UF3.11 (3A), UG3.8 (4D)
unnamed: UF2.11 (D), UG2.9 (I0), UG3.9 (4Q)
unnamed: UF2.3 (C), UG2.13 (I3), UG3.2 (1Q)
unnamed: UF2.10 (B), UG2.10 (I1), UG3.6 (3Q)
unnamed: UF2.4 (A), UG2.12 (I2), UG3.5 (2Q)
unnamed: UF4.11 (D), UG3.16 (7Q)
unnamed: UF4.3 (C), UG3.15 (6Q)
unnamed: UF4.10 (B), UG3.19 (8Q), UH5.4 (I0)
unnamed: UF4.4 (A), UG3.12 (5Q)
unnamed: UG1.3 (O), UG8.12 (D)
unnamed: UG1.2 (I1), UH5.8 (O)
unnamed: UA3.8 (O), UH5.5 (I1)
unnamed: UA3.9 (I), UG2.8 (O)
unnamed: UG3.11 (ENC), UH5.11 (O)
unnamed: UG2.2 (I1), UH2.10 (O)
NEXT: UG8.9 (Q); also elsewhere on the board
PULLUP_1: UG8.10 (PRE); also elsewhere on the board
PULLUP_2: R27.1, UG2.5 (I3)
RA9: UG2.4 (I2); also elsewhere on the board
SA0: UF6.12 (4Y); also elsewhere on the board
SA1: UF6.4 (1Y); also elsewhere on the board
SA2: UF5.9 (3Y); also elsewhere on the board
SA3: UF5.7 (2Y); also elsewhere on the board
SA4: UF5.12 (4Y); also elsewhere on the board
SA5: UF5.4 (1Y); also elsewhere on the board
SA6: UF3.4 (1Y); also elsewhere on the board
SA7: UF3.12 (4Y); also elsewhere on the board
SA8: UF3.7 (2Y); also elsewhere on the board
SA9: UF3.9 (3Y); also elsewhere on the board
SA10: UF6.9 (3Y); also elsewhere on the board
SEL8: UF1.5 (I1); also elsewhere on the board
TV_RAM_R/W: UF6.7 (2Y); also elsewhere on the board
TV_SEL: IC10.10 (I1), UA5.13 (I2), UF1.6 (O)
VIDEO_LATCH: UG8.11 (CLK); also elsewhere on the board
VIDEO_ON: UH2.11 (I); also elsewhere on the board

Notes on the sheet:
LOGIC DIAGRAM - DYNAMIC PET
DISPLAY LOGIC
To Sheet 8
SPARES
X000-X7FF
8000-8FFF
8000-87FF
!8000-87FF + WRITE + CLK 2

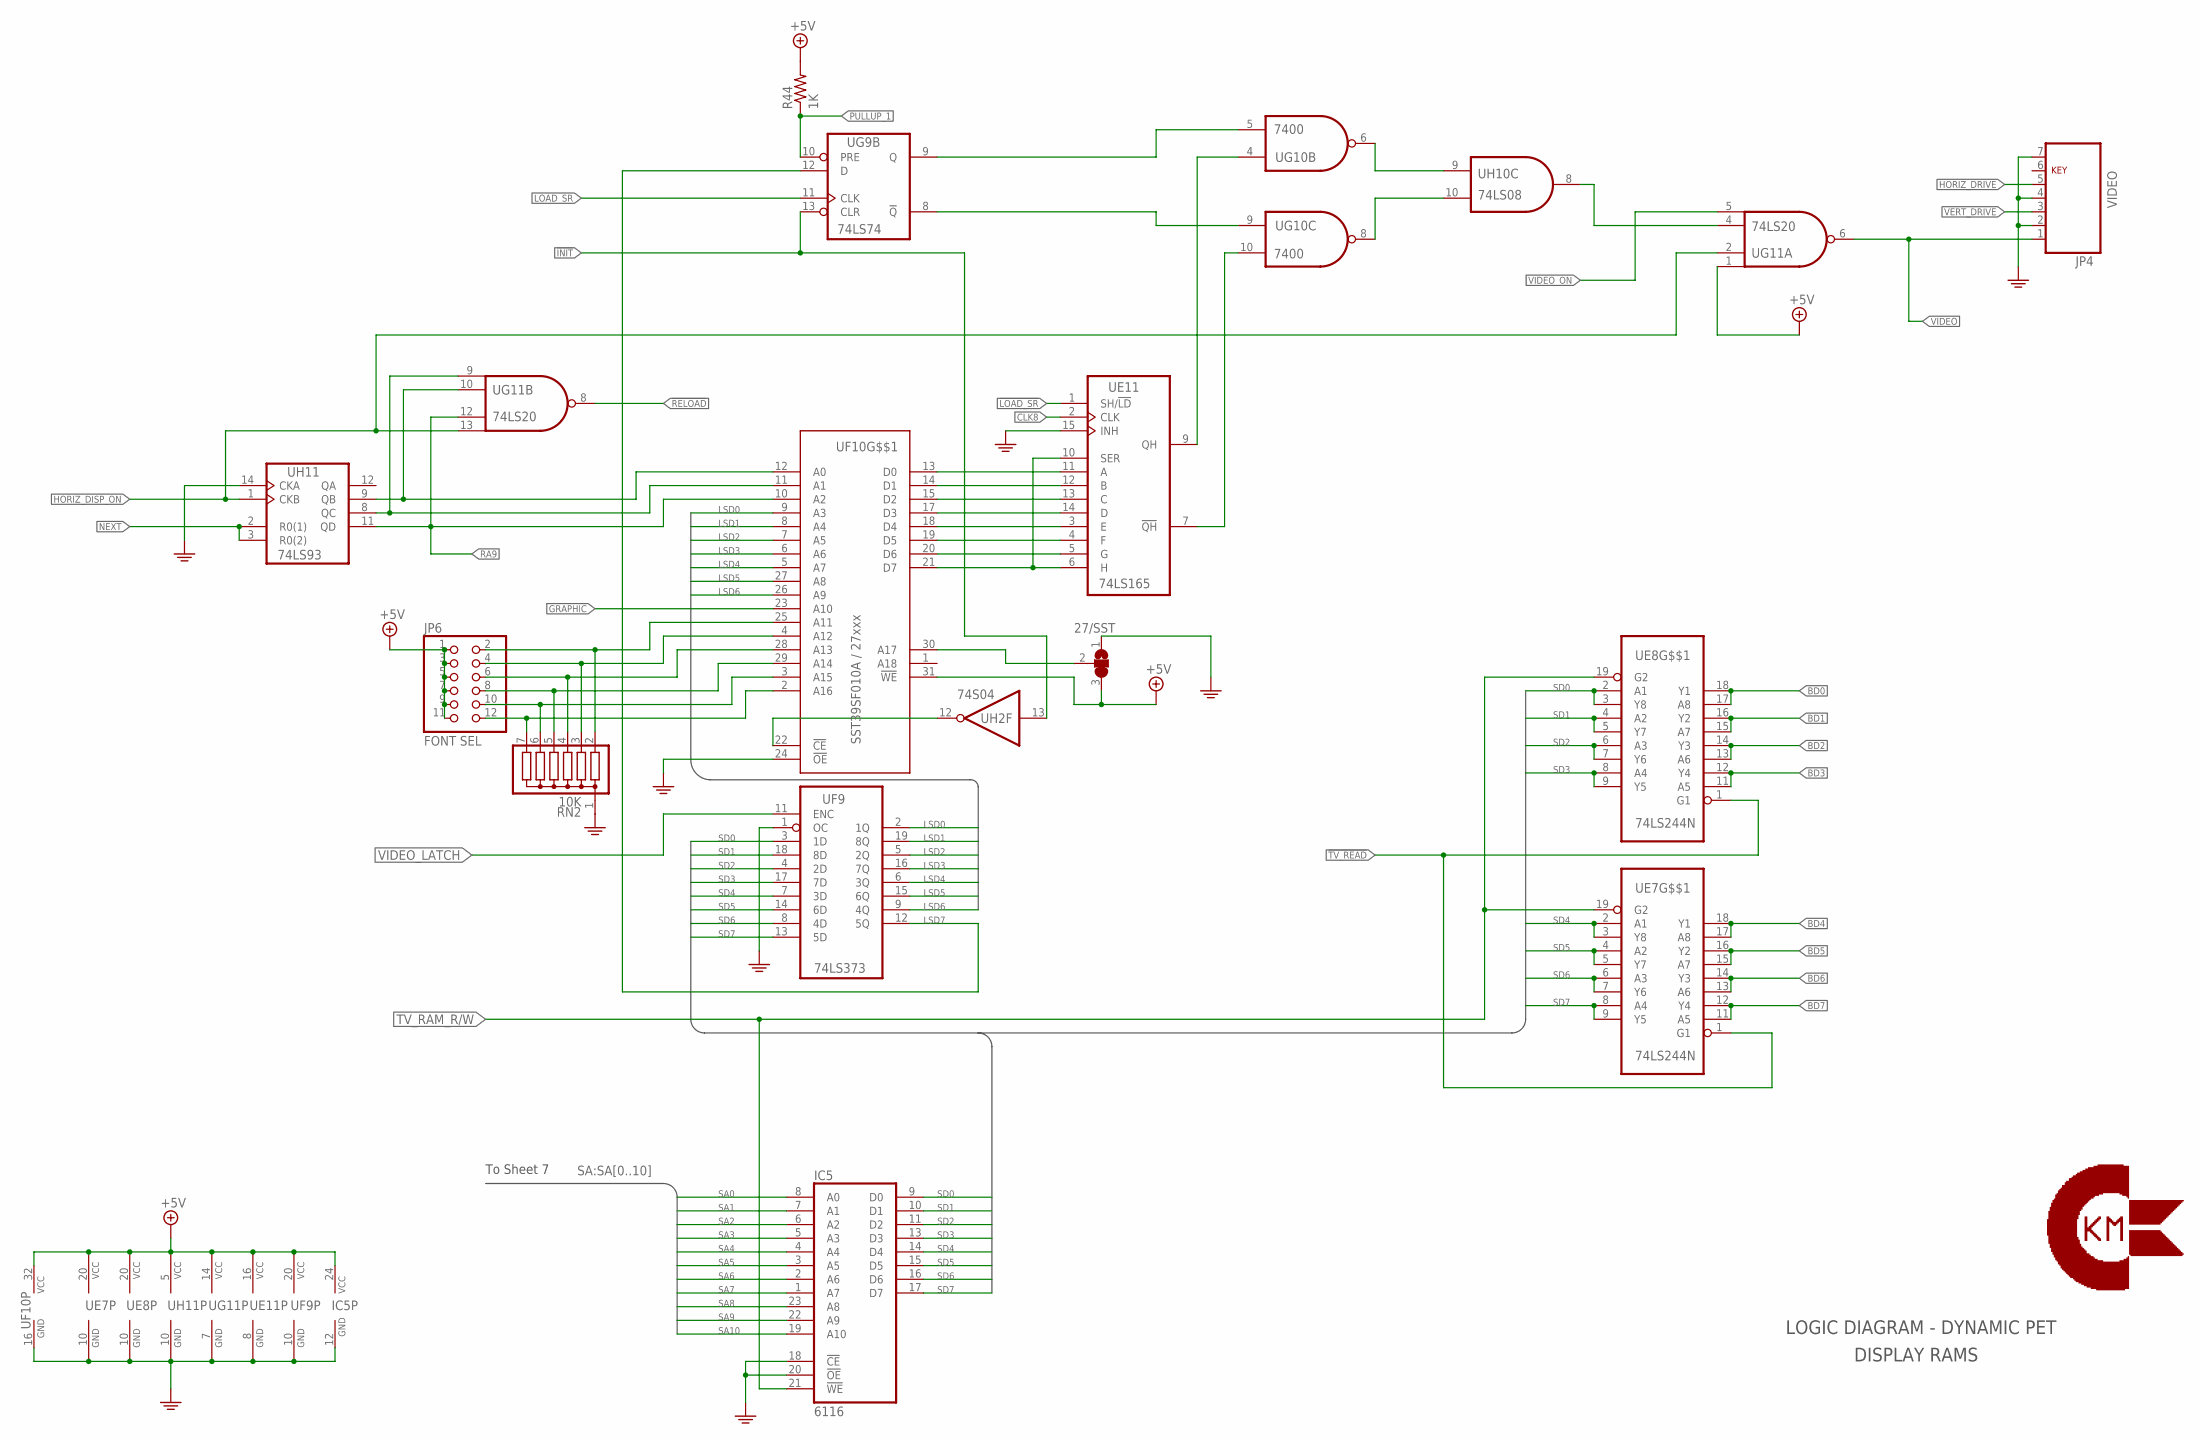
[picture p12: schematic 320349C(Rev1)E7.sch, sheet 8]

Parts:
IC5: 6116; DIL24
JP4: VIDEO; 1X07
JP6: FONT SEL; 2X06
R44: 1K; 0207/10
RN2: 10K; SIL7
SJ1: 27/SST; SJ_2
UE7, UE8: 74LS244N; DIL20
UE11: 74LS165; DIL16
UF9: 74LS373; DIL20
UF10: SST39SF010A / 27xxx; SST39SF010A
UG9: 74LS74; DIL14
UG10: 7400; DIL14
UG11: 74LS20; DIL14
UH2: 74S04; DIL14
UH10: 74LS08; DIL14
UH11: 74LS93; DIL14

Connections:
!INIT: UG9.13 (CLR), UH2.13 (I); also elsewhere on the board
!LOAD_SR: UE11.1 (SH/!LD); also elsewhere on the board
!RELOAD: UG11.8 (O); also elsewhere on the board
!TV_READ: UE7.1 (G1), UE8.1 (G1); also elsewhere on the board
+5V: IC5.24 (VCC), JP6.1, JP6.3, JP6.5, JP6.7, JP6.9, JP6.11, R44.2, SJ1.3, UE7.20 (VCC), UE8.20 (VCC), UE11.16 (VCC), UF9.20 (VCC), UF10.31 (!WE), UF10.32 (VCC), UG11.1 (I0), UG11.14 (VCC), UH11.5 (VCC); also elsewhere on the board
BD0: UE8.17 (A8), UE8.18 (Y1); also elsewhere on the board
BD1: UE8.15 (A7), UE8.16 (Y2); also elsewhere on the board
BD2: UE8.13 (A6), UE8.14 (Y3); also elsewhere on the board
BD3: UE8.11 (A5), UE8.12 (Y4); also elsewhere on the board
BD4: UE7.17 (A8), UE7.18 (Y1); also elsewhere on the board
BD5: UE7.15 (A7), UE7.16 (Y2); also elsewhere on the board
BD6: UE7.13 (A6), UE7.14 (Y3); also elsewhere on the board
BD7: UE7.11 (A5), UE7.12 (Y4); also elsewhere on the board
CLK8: UE11.2 (CLK); also elsewhere on the board
GND: IC5.12 (GND), IC5.18 (!CE), IC5.20 (!OE), JP4.2, JP4.4, JP4.7, RN2.1, SJ1.1, UE7.10 (GND), UE8.10 (GND), UE11.8 (GND), UE11.15 (INH), UF9.1 (OC), UF9.10 (GND), UF10.16 (GND), UF10.24 (!OE), UG11.7 (GND), UH11.10 (GND), UH11.14 (CKA); also elsewhere on the board
GRAPHIC: UF10.23 (A10); also elsewhere on the board
HORIZ_DISP_ON: UG11.2 (I1), UG11.13 (I3), UH11.1 (CKB); also elsewhere on the board
HORIZ_DRIVE: JP4.5; also elsewhere on the board
LOAD_SR: UG9.11 (CLK); also elsewhere on the board
LSD0: UF9.2 (1Q), UF10.9 (A3)
LSD1: UF9.19 (8Q), UF10.8 (A4)
LSD2: UF9.5 (2Q), UF10.7 (A5)
LSD3: UF9.16 (7Q), UF10.6 (A6)
LSD4: UF9.6 (3Q), UF10.5 (A7)
LSD5: UF9.15 (6Q), UF10.27 (A8)
LSD6: UF9.9 (4Q), UF10.26 (A9)
LSD7: UF9.12 (5Q), UG9.12 (D)
unnamed: UF10.22 (!CE), UH2.12 (O)
unnamed: JP6.2, RN2.2, UF10.25 (A11)
unnamed: JP6.4, RN2.3, UF10.4 (A12)
unnamed: JP6.6, RN2.4, UF10.28 (A13)
unnamed: JP6.8, RN2.5, UF10.29 (A14)
unnamed: UF10.11 (A1), UG11.9 (I0), UH11.8 (QC)
unnamed: JP6.10, RN2.6, UF10.3 (A15)
unnamed: JP6.12, RN2.7, UF10.2 (A16)
unnamed: SJ1.2, UF10.30 (A17)
unnamed: UG11.4 (I2), UH10.8 (O)
unnamed: UG9.9 (Q), UG10.5 (I1)
unnamed: UG9.8 (!Q), UG10.9 (I0)
unnamed: UG10.8 (O), UH10.10 (I1)
unnamed: UG10.6 (O), UH10.9 (I0)
unnamed: UE11.7 (!QH), UG10.10 (I1)
unnamed: UE11.9 (QH), UG10.4 (I0)
unnamed: UE11.11 (A), UF10.13 (D0)
unnamed: UE11.12 (B), UF10.14 (D1)
unnamed: UE11.13 (C), UF10.15 (D2)
unnamed: UE11.14 (D), UF10.17 (D3)
unnamed: UE11.3 (E), UF10.18 (D4)
unnamed: UE11.4 (F), UF10.19 (D5)
unnamed: UE11.5 (G), UF10.20 (D6)
unnamed: UE11.6 (H), UE11.10 (SER), UF10.21 (D7)
NEXT: UH11.2 (R0(1)), UH11.3 (R0(2)); also elsewhere on the board
PULLUP_1: R44.1, UG9.10 (PRE); also elsewhere on the board
RA7: UF10.12 (A0), UG11.10 (I1), UH11.9 (QB)
RA9: UF10.10 (A2), UG11.12 (I2), UH11.11 (QD); also elsewhere on the board
SA0: IC5.8 (A0); also elsewhere on the board
SA1: IC5.7 (A1); also elsewhere on the board
SA2: IC5.6 (A2); also elsewhere on the board
SA3: IC5.5 (A3); also elsewhere on the board
SA4: IC5.4 (A4); also elsewhere on the board
SA5: IC5.3 (A5); also elsewhere on the board
SA6: IC5.2 (A6); also elsewhere on the board
SA7: IC5.1 (A7); also elsewhere on the board
SA8: IC5.23 (A8); also elsewhere on the board
SA9: IC5.22 (A9); also elsewhere on the board
SA10: IC5.19 (A10); also elsewhere on the board
SD0: IC5.9 (D0), UE8.2 (A1), UE8.3 (Y8), UF9.3 (1D)
SD1: IC5.10 (D1), UE8.4 (A2), UE8.5 (Y7), UF9.18 (8D)
SD2: IC5.11 (D2), UE8.6 (A3), UE8.7 (Y6), UF9.4 (2D)
SD3: IC5.13 (D3), UE8.8 (A4), UE8.9 (Y5), UF9.17 (7D)
SD4: IC5.14 (D4), UE7.2 (A1), UE7.3 (Y8), UF9.7 (3D)
SD5: IC5.15 (D5), UE7.4 (A2), UE7.5 (Y7), UF9.14 (6D)
SD6: IC5.16 (D6), UE7.6 (A3), UE7.7 (Y6), UF9.8 (4D)
SD7: IC5.17 (D7), UE7.8 (A4), UE7.9 (Y5), UF9.13 (5D)
TV_RAM_R/W: IC5.21 (!WE), UE7.19 (G2), UE8.19 (G2); also elsewhere on the board
VERT_DRIVE: JP4.3; also elsewhere on the board
VIDEO: JP4.1, UG11.6 (O); also elsewhere on the board
VIDEO_LATCH: UF9.11 (ENC); also elsewhere on the board
VIDEO_ON: UG11.5 (I3); also elsewhere on the board

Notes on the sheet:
LOGIC DIAGRAM - DYNAMIC PET
DISPLAY RAMS
To Sheet 7
KEY

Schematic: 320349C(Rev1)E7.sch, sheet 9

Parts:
9V: PINHD-1X1; 1X01
+5V: PINHD-1X1; 1X01
+5V1: +5V; 1X01
C1, C2, C3, C4, C5, C6, C7, C8, C9, C10, C11, C12, C13, C18, C19, C20, C21, C22, C23, C24, C25, C26, C27, C28, C29, C30, C31, C32, C33, C34, C35, C36, C37, C38, C39, C40, C41, C42, C45, C46, C49, C50, C51, C52, C53, C54, C55, C56, C77, C78, C79, C80, C91, C92, C93: 0.1uF/50; C025-025X050
C14: 47uF/16; E2,5-6
C17: 1.0uF/25; E1,8-4
CR10: 1N4001; DO41-10
GND2, GND3, GND4: GND; 1X01
J4: POWER_JACKPTH; POWER_JACK_PTH
KEY: Key; 1X01
LED: PINHD-1X2; 1X02
LED1: +9V; LED5MM
LED2: +5V; LED5MM
R20: 470; 0207/10
R21: 220; 0207/10
S1: 320-938; 320-938H
V7805: VREG_78XXL

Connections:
+5V: +5V.1, +5V1.1, C1.1, C2.1, C3.1, C4.1, C5.1, C6.1, C7.1, C8.1, C9.1, C10.1, C11.1, C12.1, C13.1, C14.+, C18.1, C19.1, C20.1, C21.1, C22.1, C23.1, C24.1, C25.1, C26.1, C27.1, C28.1, C29.1, C30.1, C31.1, C32.1, C33.1, C34.1, C35.1, C36.1, C37.1, C38.1, C39.1, C40.1, C41.1, C42.1, C45.1, C46.1, C49.1, C50.1, C51.1, C52.1, C53.1, C54.1, C55.1, C56.1, C77.1, C78.1, C79.1, C80.1, C91.1, C92.1, C93.1, CR10.A, R21.2, V7805.OUT; also elsewhere on the board
+9V_UNREG: 9V.1, C17.+, CR10.C, R20.2, S1.2, S1.5, V7805.IN; also elsewhere on the board
GND: C1.2, C2.2, C3.2, C4.2, C5.2, C6.2, C7.2, C8.2, C9.2, C10.2, C11.2, C12.2, C13.2, C14.-, C17.-, C18.2, C19.2, C20.2, C21.2, C22.2, C23.2, C24.2, C25.2, C26.2, C27.2, C28.2, C29.2, C30.2, C31.2, C32.2, C33.2, C34.2, C35.2, C36.2, C37.2, C38.2, C39.2, C40.2, C41.2, C42.2, C45.2, C46.2, C49.2, C50.2, C51.2, C52.2, C53.2, C54.2, C55.2, C56.2, C77.2, C78.2, C79.2, C80.2, C91.2, C92.2, C93.2, GND2.1, GND3.1, GND4.1, J4.GND, LED.2, LED1.K (C), LED2.K (C), V7805.GND; also elsewhere on the board
unnamed: LED1.A, R20.1
unnamed: LED.1, LED2.A, R21.1
unnamed: J4.PWR, S1.3 (S), S1.6 (S)

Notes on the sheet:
LOGIC DIAGRAM - DYNAMIC PET
VOLTAGE REGULATOR

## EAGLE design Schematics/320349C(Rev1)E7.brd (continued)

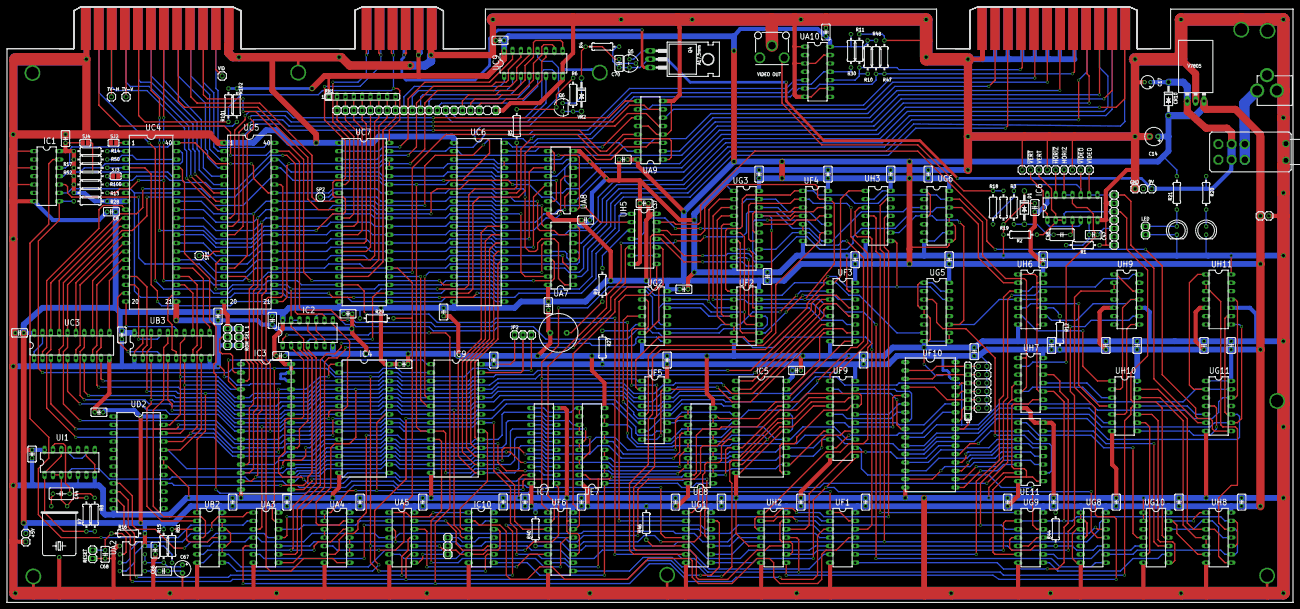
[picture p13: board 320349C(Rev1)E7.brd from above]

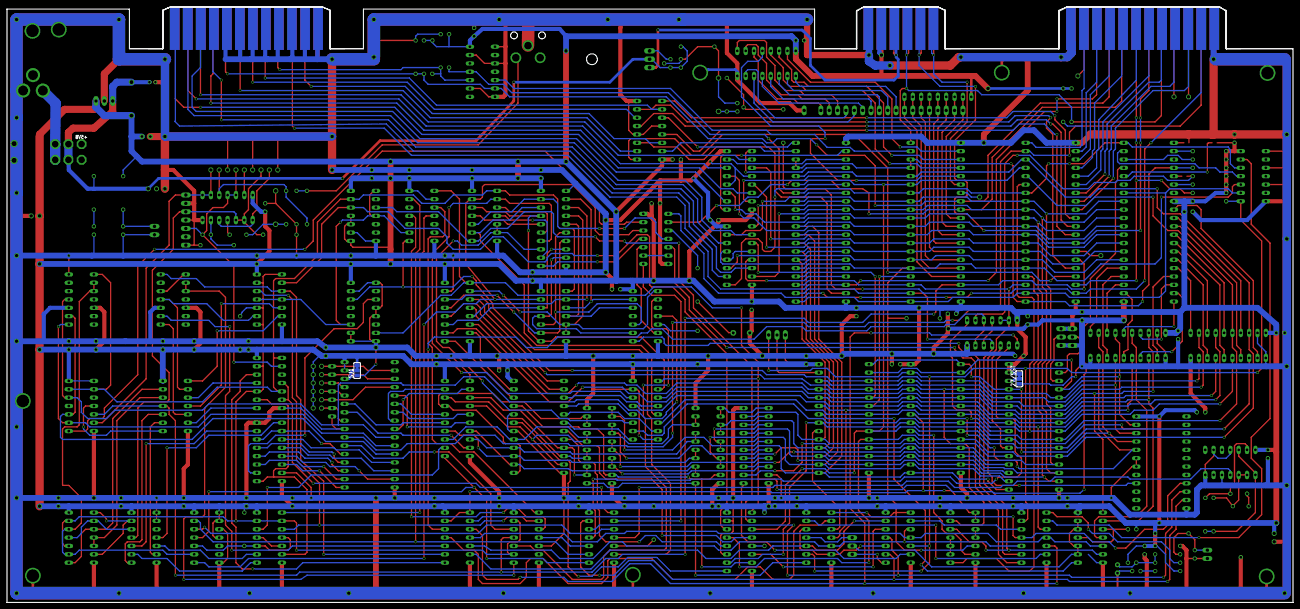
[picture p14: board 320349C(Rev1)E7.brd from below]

Board: 2 copper layers, 390.9 x 181.0 mm, 211 parts (2 on the bottom side), 331 nets.
